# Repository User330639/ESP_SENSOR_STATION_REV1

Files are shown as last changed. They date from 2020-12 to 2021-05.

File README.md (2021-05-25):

# ESP_SENSOR_STATION_REV1
## Аннотация
Курсовой проект. ESP8622 (модуль ESP-12E) с набором датчиков:
 * Датчик температуры на основе SHT10
 * Датчик влажности на основе SHT10
 * Датчик концентрации пыли - AFE на AD7792
 * Датчик давления - AFE на AD7792
 * Датчик концентрации C3H8 - AFE на AD7792 
 
Основные особенности:
 * Питание от USB и/или от сети 230VAC, переключение между источниками без прерывания работы устройства
 * Программирование напрямую из среды разработки: BOOT и RESET ESP-12E управляются через RTS и DTR преобразователя USB-UART
 * Измерение концентрации C3H8 с применением прецизионного источника тока

Если опустить ряд низкоуровневых подробностей, софт занимается сбором данных с датчиков и по запросу выдает HTML страницу, содержащую примитивный интерфейс, в котором отображаются их показания. **Программная часть проекта не претендует на законченность и является в б*о*льшей мере демонстрацией возможностей устройства.**

## Структура репозитория
Репозиторий содержит 3 папки:  
**HW** - папка с проектом аппаратной части; выходные данные для производства содержатся в подкаталоге OUT.  
**SW** - папка с проектом программной части.  
**MECH** - проект корпуса устройства.  
Структура репозитория может претерпевать изменения по мере развития проекта.

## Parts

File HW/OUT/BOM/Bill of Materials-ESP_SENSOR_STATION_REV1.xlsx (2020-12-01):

LibRef | Description | Designator | Quantity
GRM188R61A226ME15D |  | C1, C2, C3, C4, C5, C6, C7, C9, C10, C11, C12, C13, C14, C15, C16 | 15
GRM1885C2A102JA01D |  | C8, C17, C18 | 3
GP2Y1010AU0F |  | DA1 | 1
AD7792 |  | DA2 | 1
IRM-05-5 |  | DA3 | 1
TPS2113APW |  | DA4 | 1
ADP3338AKCZ-3.3RL7 |  | DA5 | 1
MPXHZ6400AC6T1 |  | DA6 | 1
SHT10 |  | DA7 | 1
MP-5 |  | DA8 | 1
ESP-12E |  | DD1 | 1
CP2102-GMR |  | DD2 | 1
BLM18PG471SN1D |  | FB1, FB2 | 2
PKM22EPPH4007-B0 |  | Q1 | 1
RC0603FR-074K7L |  | R1, R3, R4, R5, R6, R9, R11, R12, R20, R25, R30, R35 | 12
RC0603FR-070RL |  | R2, R8, R27, R34, R36 | 5
RC0603FR-07510RL |  | R7 | 1
RC0603FR-071KL |  | R10, R21, R26 | 3
RC0603FR-07120RL |  | R13, R14, R15, R16, R17, R18, R19, R22, R23, R24, R28, R29, R31, R32, R33 | 15
B72214S0251K101 |  | RV1, RV2, RV3 | 3
5011 |  | TP1, TP2 | 2
GNL-3012GD |  | VD1 | 1
GNL-3012ED |  | VD2 | 1
SP0503BAHTG |  | VD3 | 1
2N7002LT1G |  | VT1, VT3, VT4, VT5 | 4
BC847BDW1T1G |  | VT2 | 1
300-031-12 |  | XS1 | 1
1734035-1 |  | XS2 | 1
B6B-ZR-SM4-TF(LF)(SN) |  | XS3 | 1

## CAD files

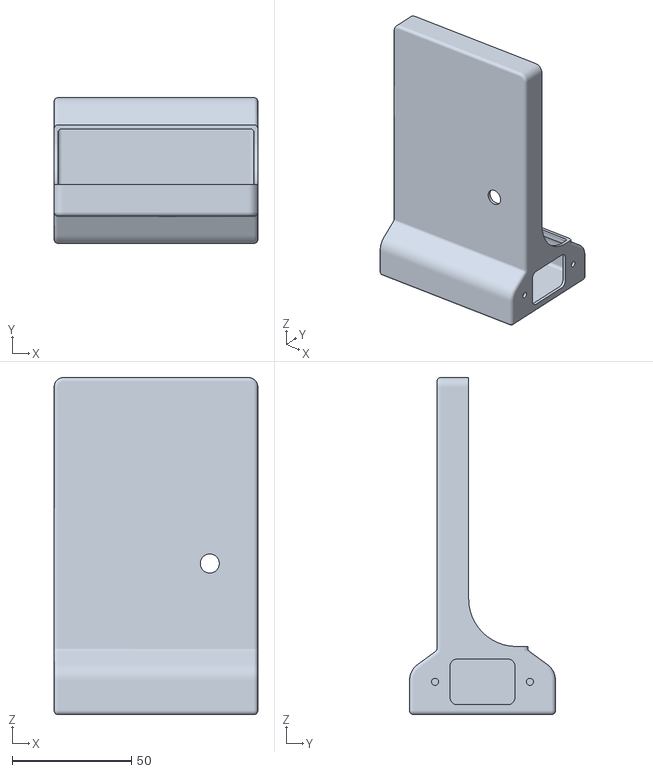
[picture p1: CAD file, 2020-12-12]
MECH/Основание.stl
85.5 x 61.2 x 141.5

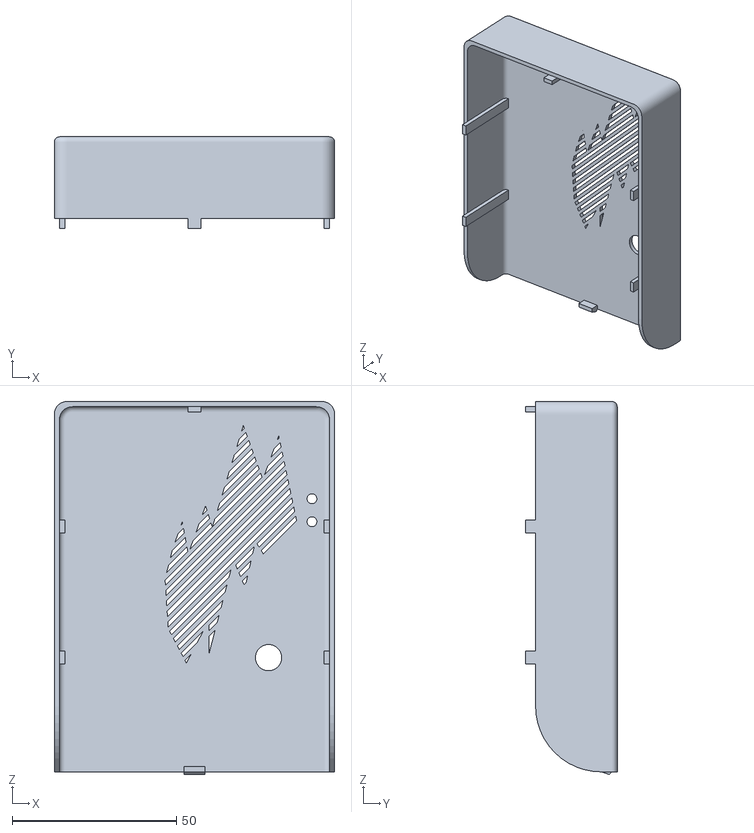
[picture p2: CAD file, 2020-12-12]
MECH/Крышка.stl
85.5 x 27.9 x 113.7

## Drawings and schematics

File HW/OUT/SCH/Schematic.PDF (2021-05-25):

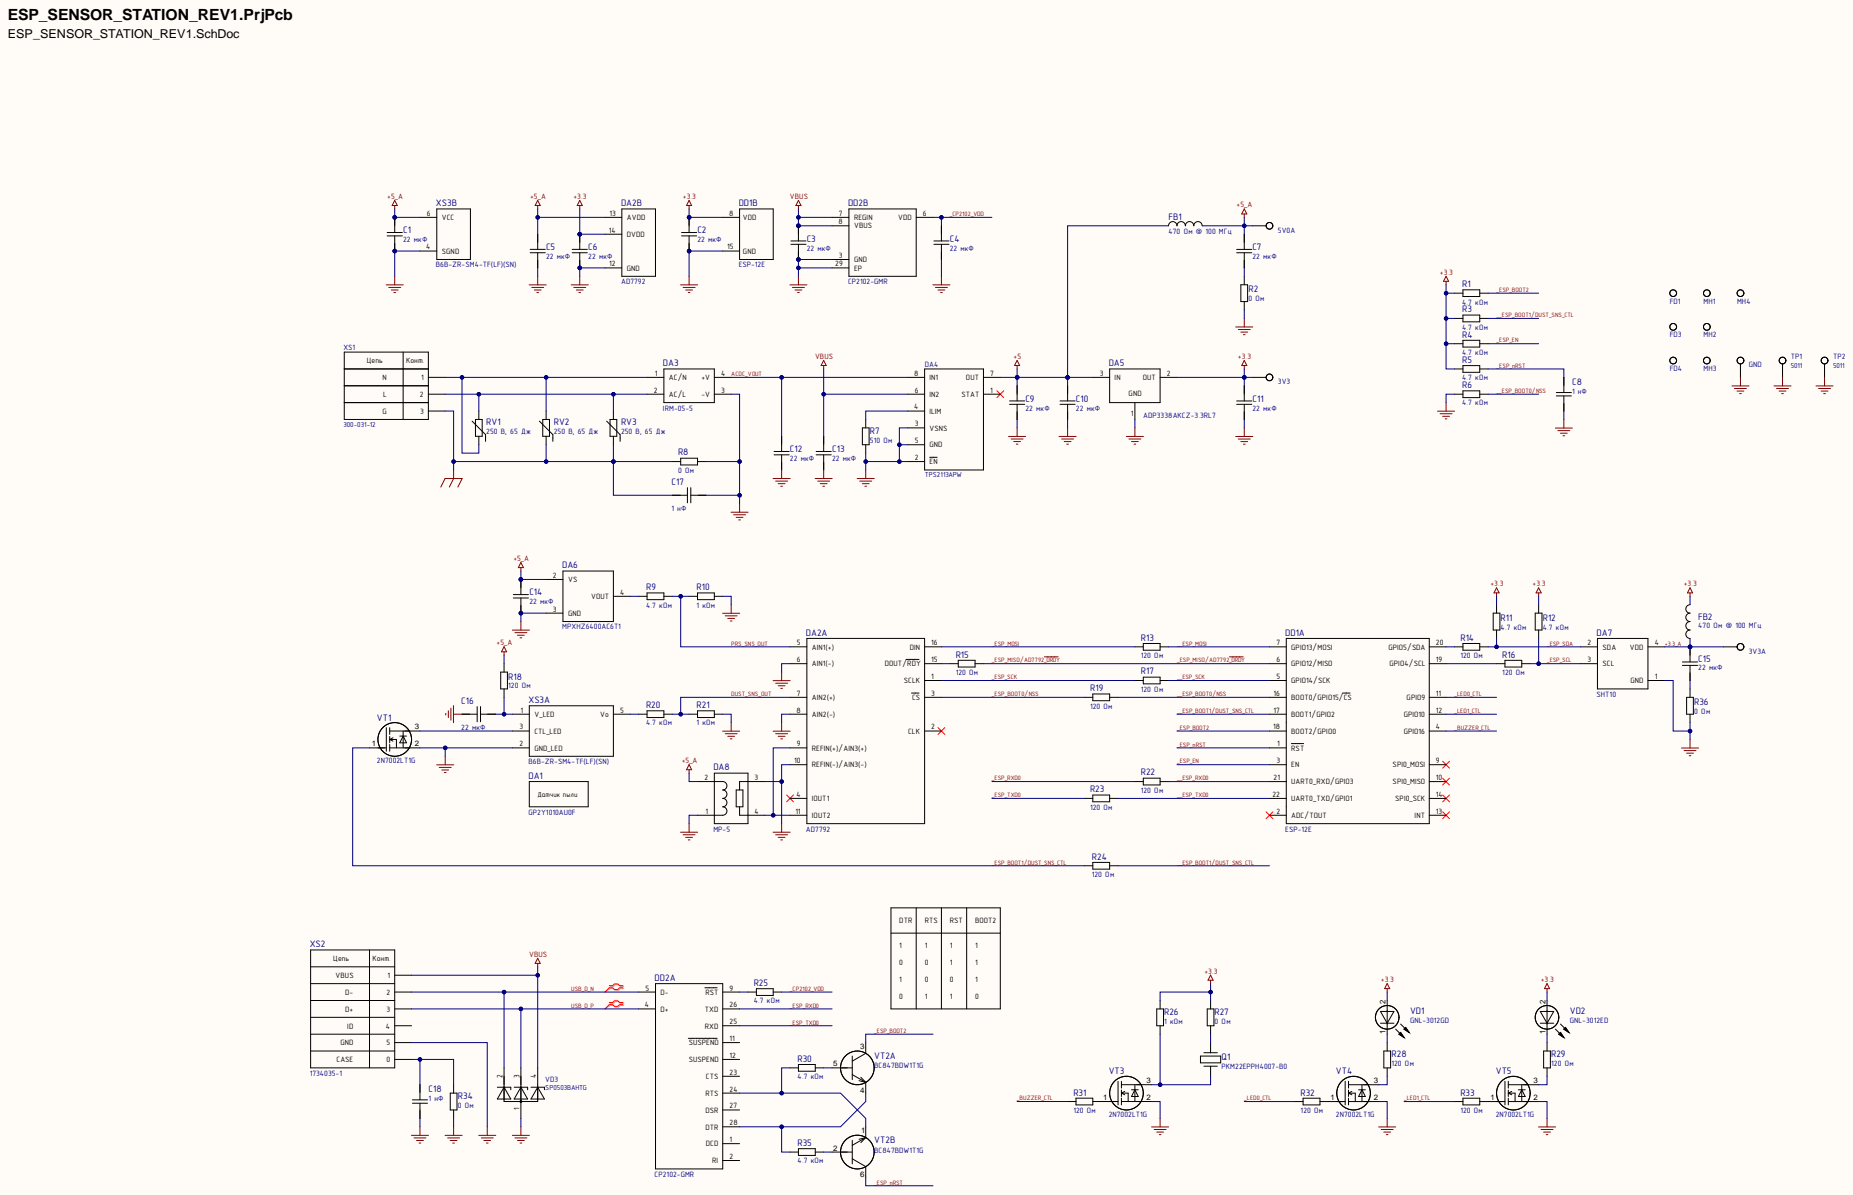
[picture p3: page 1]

ILIM 4

VSNS 3

GND 5

2 | GND_LED 2

REFIN(-)/AIN3(-) 10

IOUT2 11 | | ADC/TOUT 2

DTR | RTS | RST | BOOT2

Цепь | Конт.

VBUS | 1

USB_D_P | D+ 4 | _ESP_RXD0

GND | 5

CASE | 0

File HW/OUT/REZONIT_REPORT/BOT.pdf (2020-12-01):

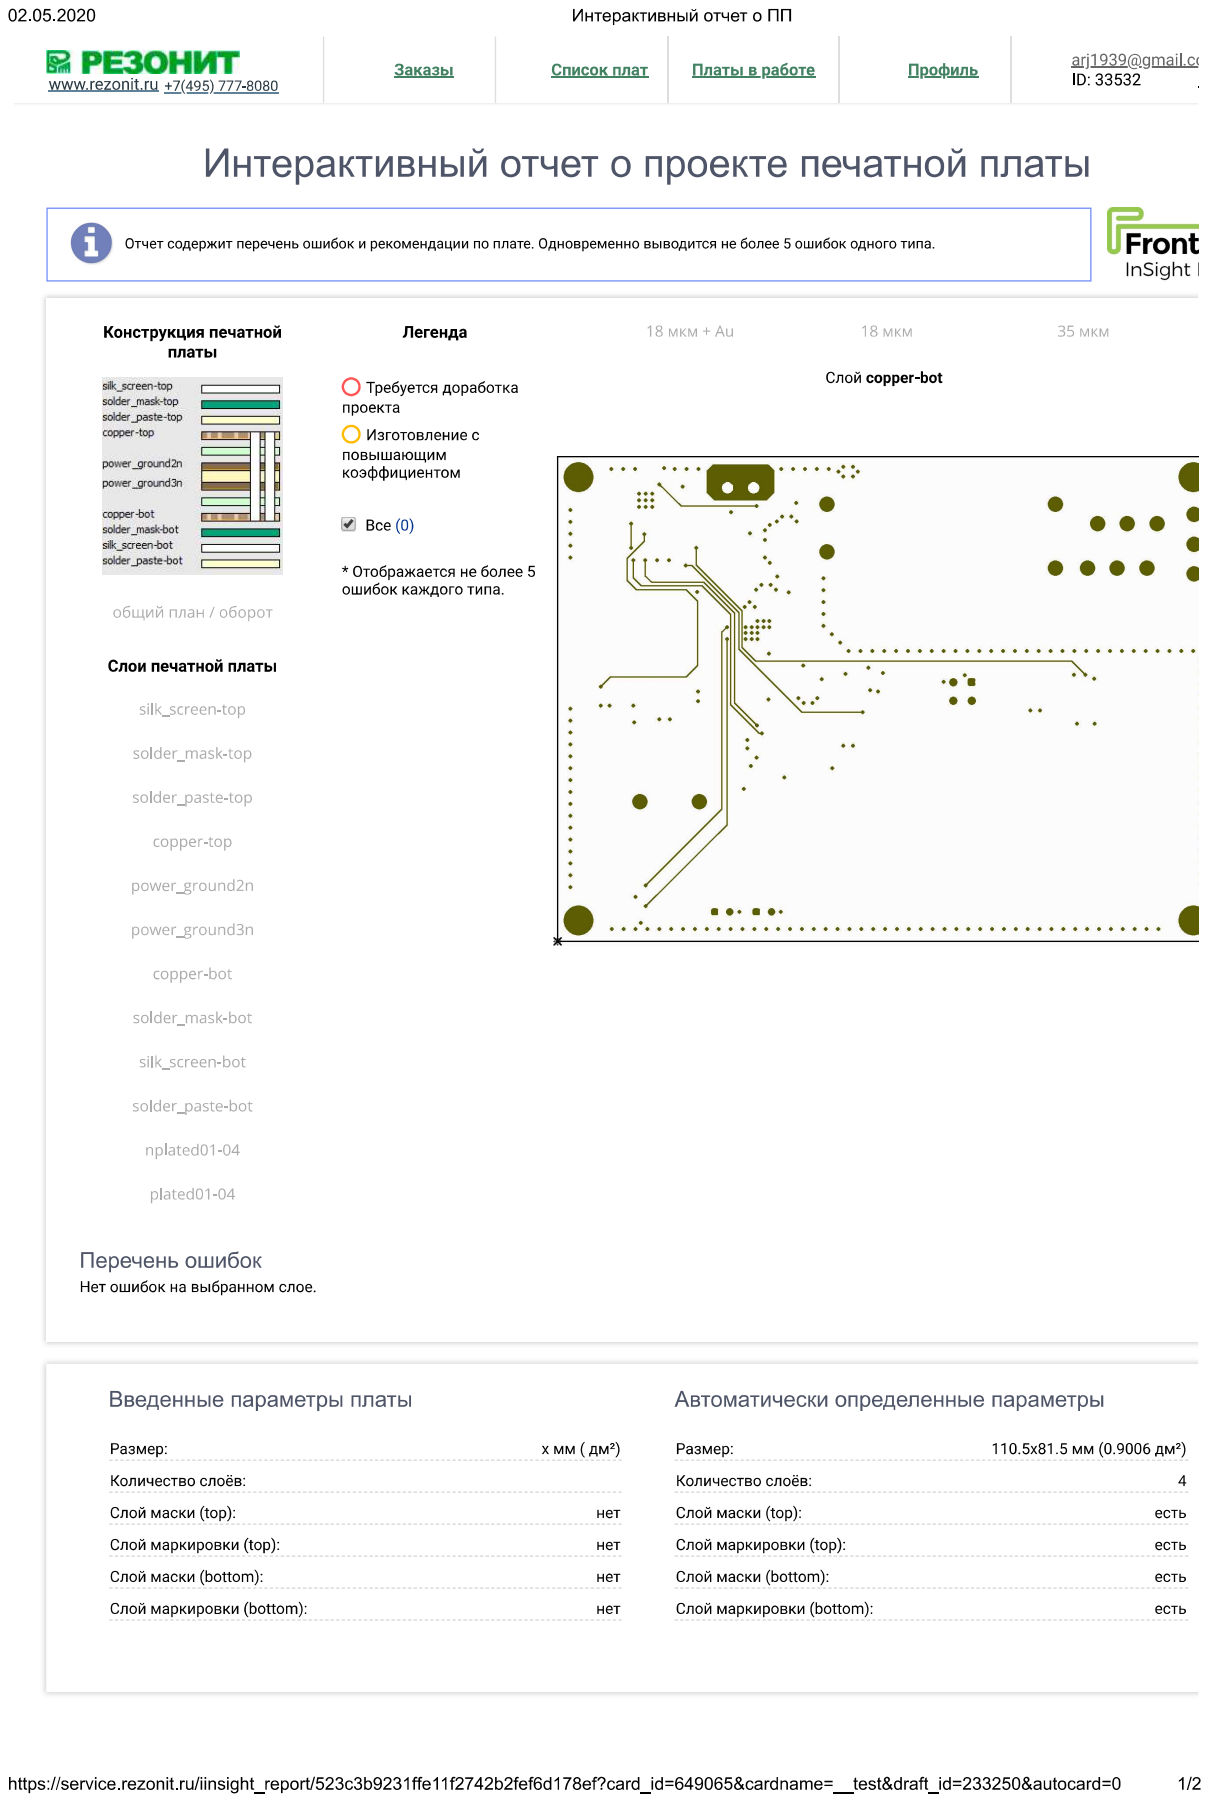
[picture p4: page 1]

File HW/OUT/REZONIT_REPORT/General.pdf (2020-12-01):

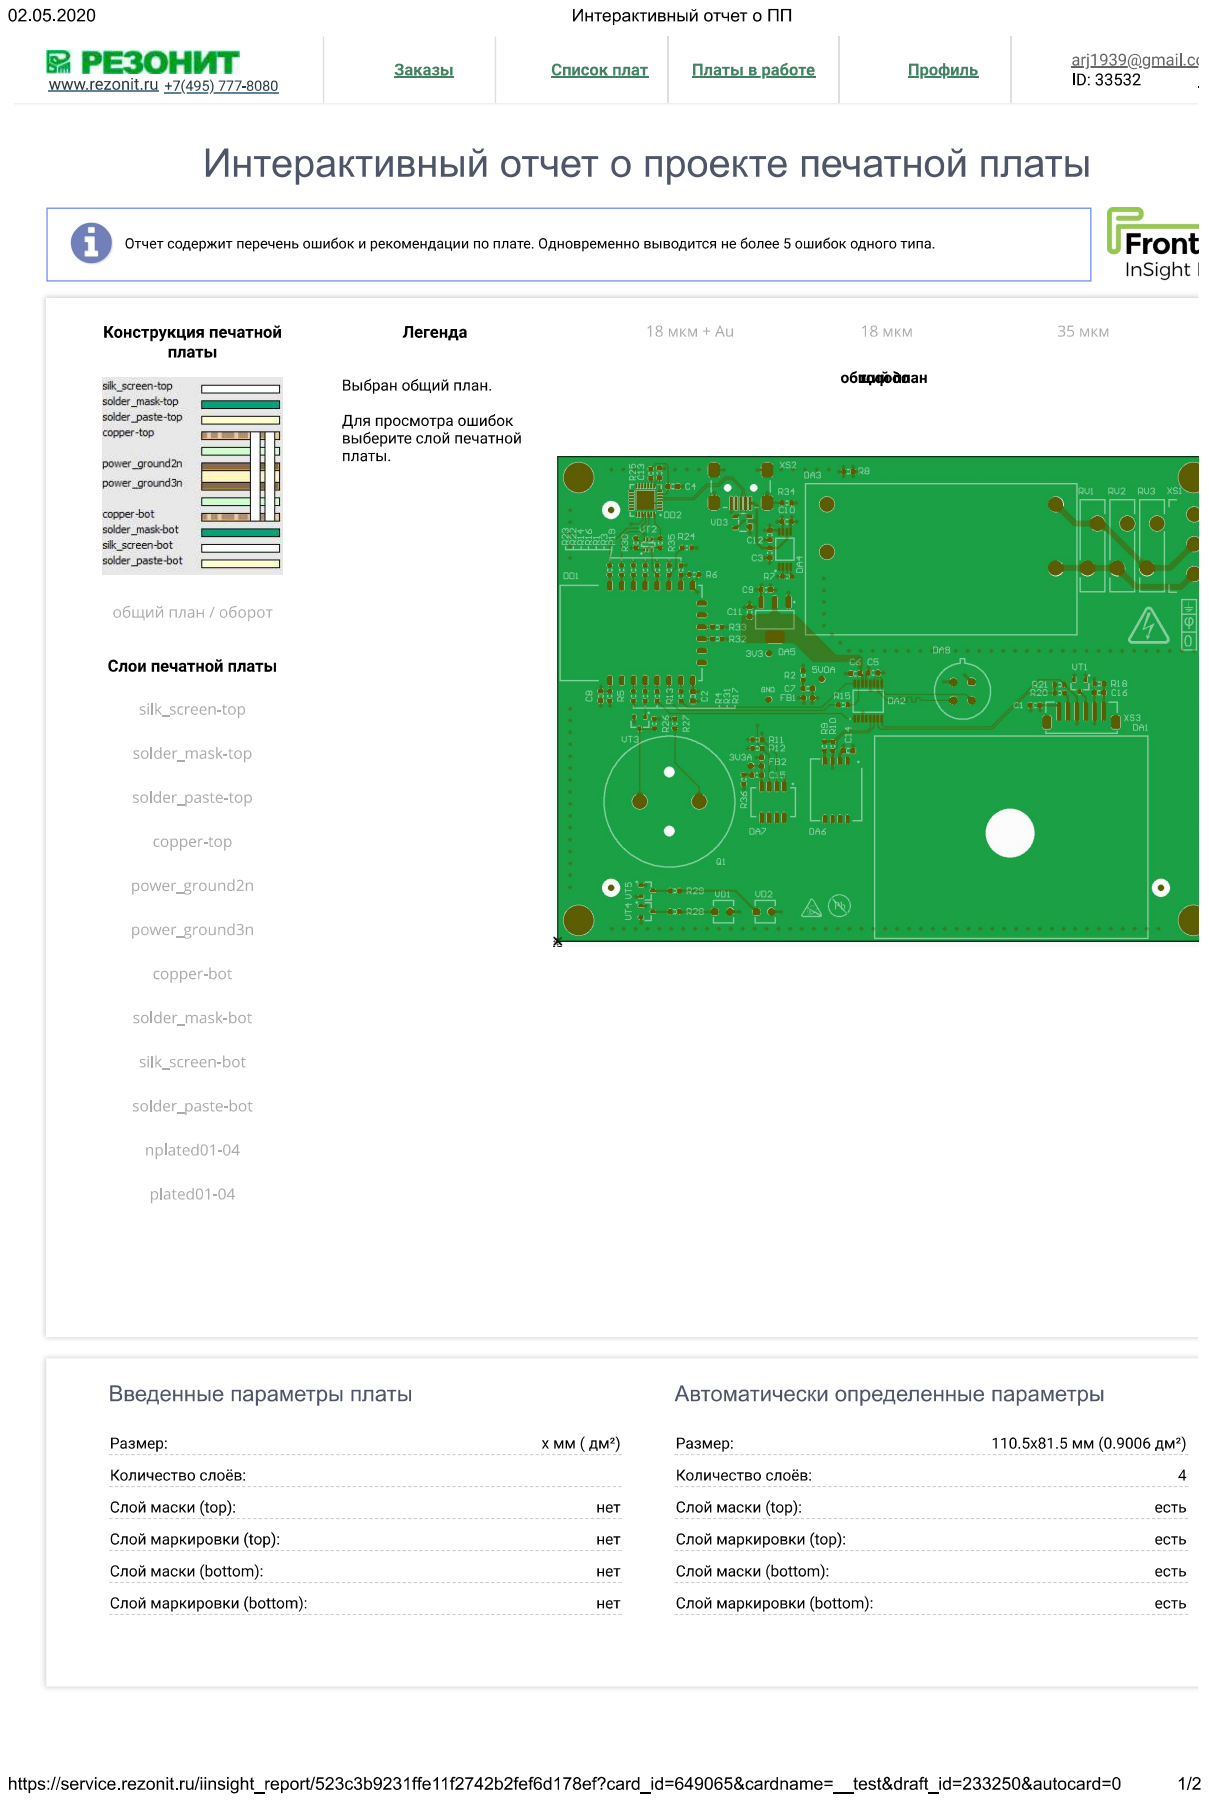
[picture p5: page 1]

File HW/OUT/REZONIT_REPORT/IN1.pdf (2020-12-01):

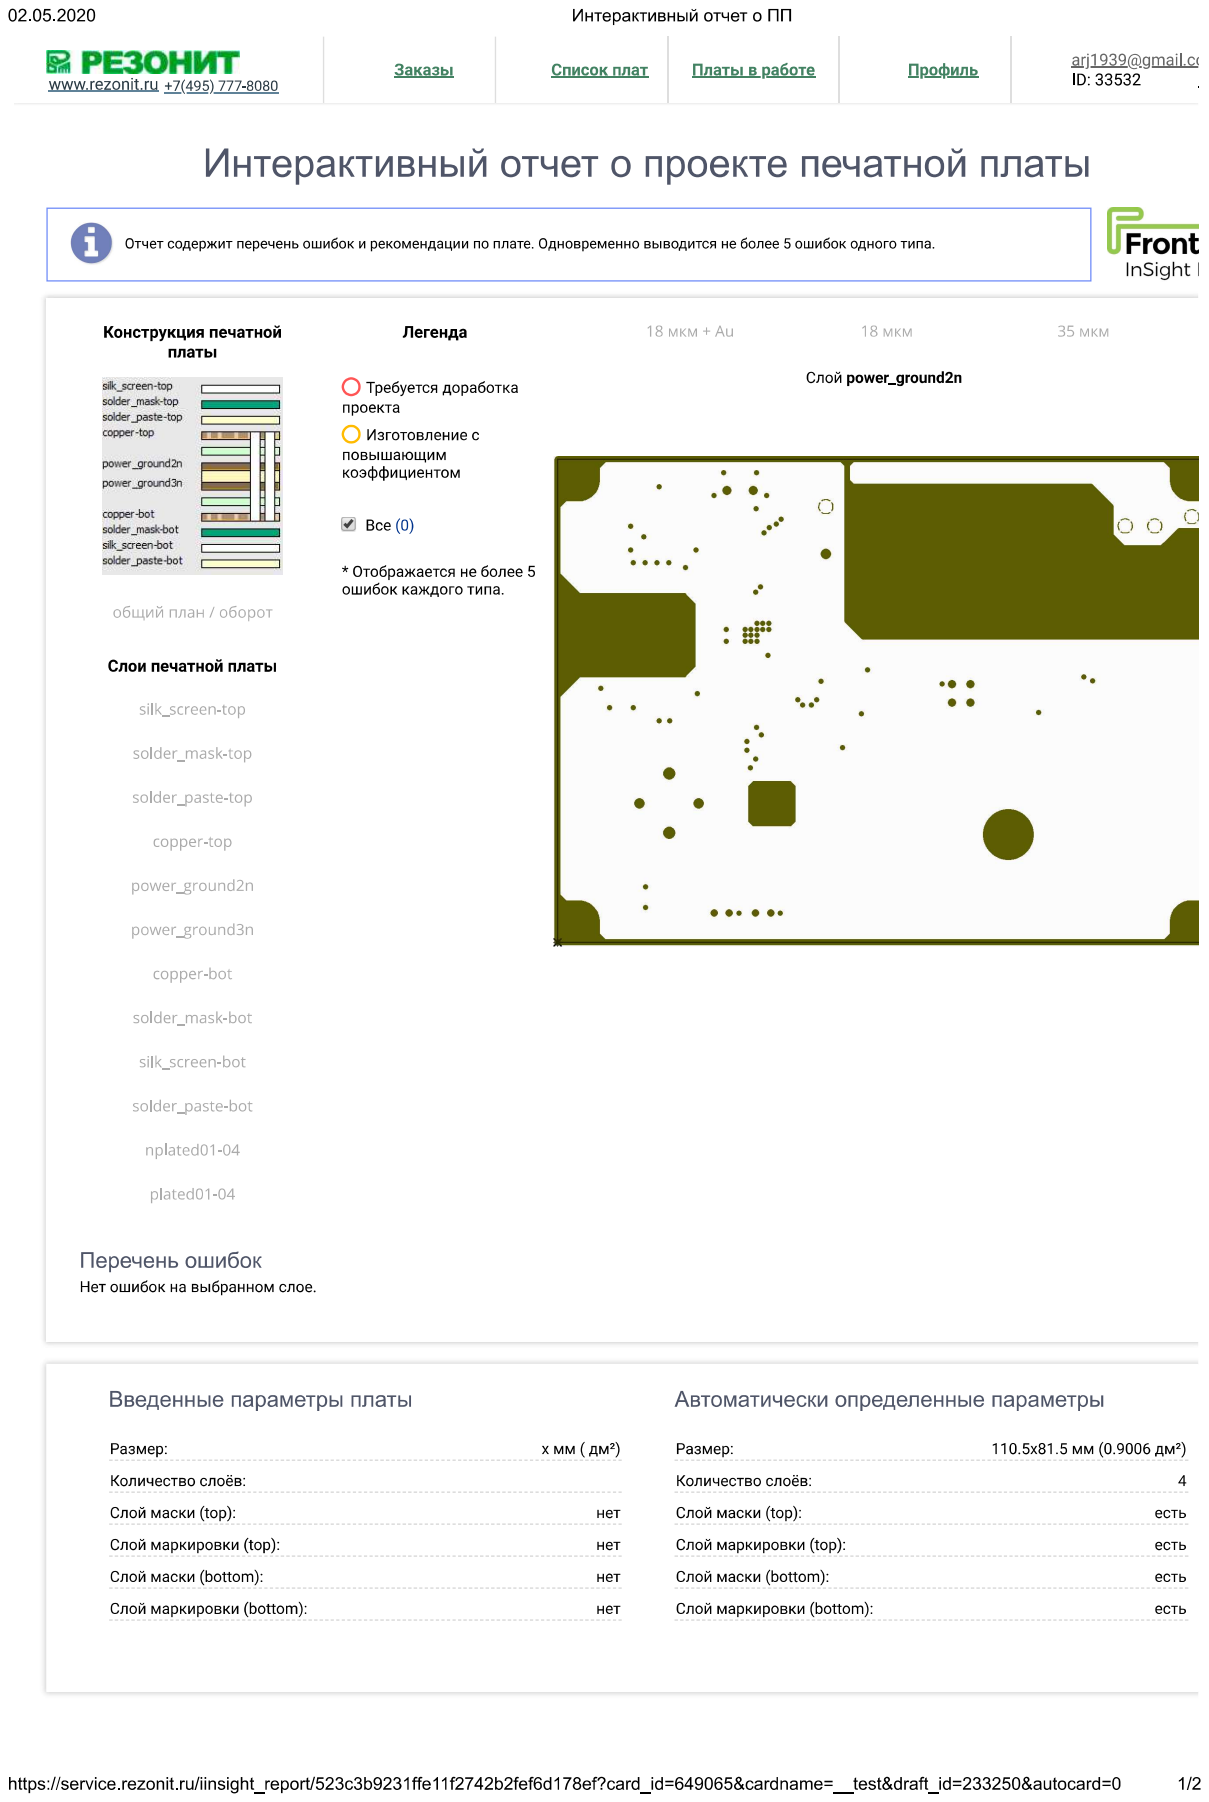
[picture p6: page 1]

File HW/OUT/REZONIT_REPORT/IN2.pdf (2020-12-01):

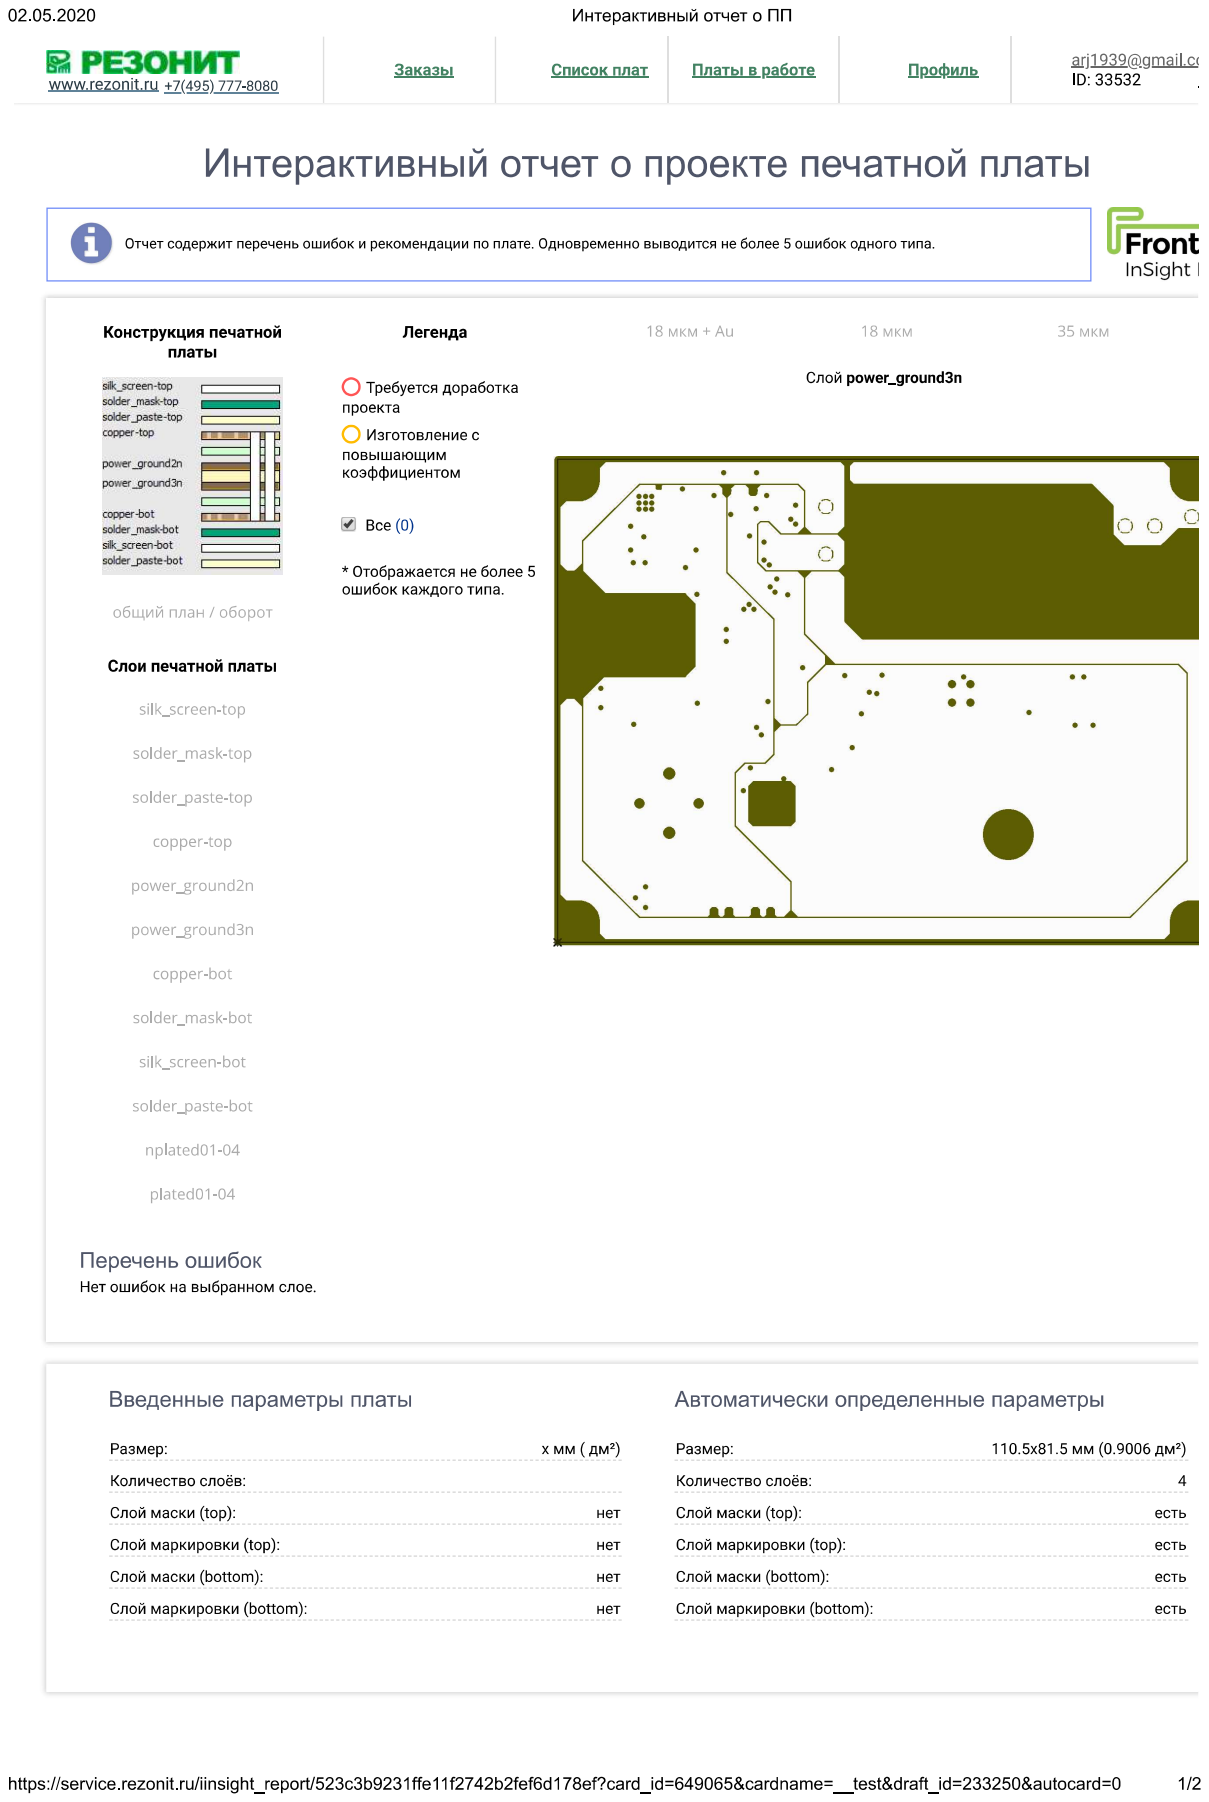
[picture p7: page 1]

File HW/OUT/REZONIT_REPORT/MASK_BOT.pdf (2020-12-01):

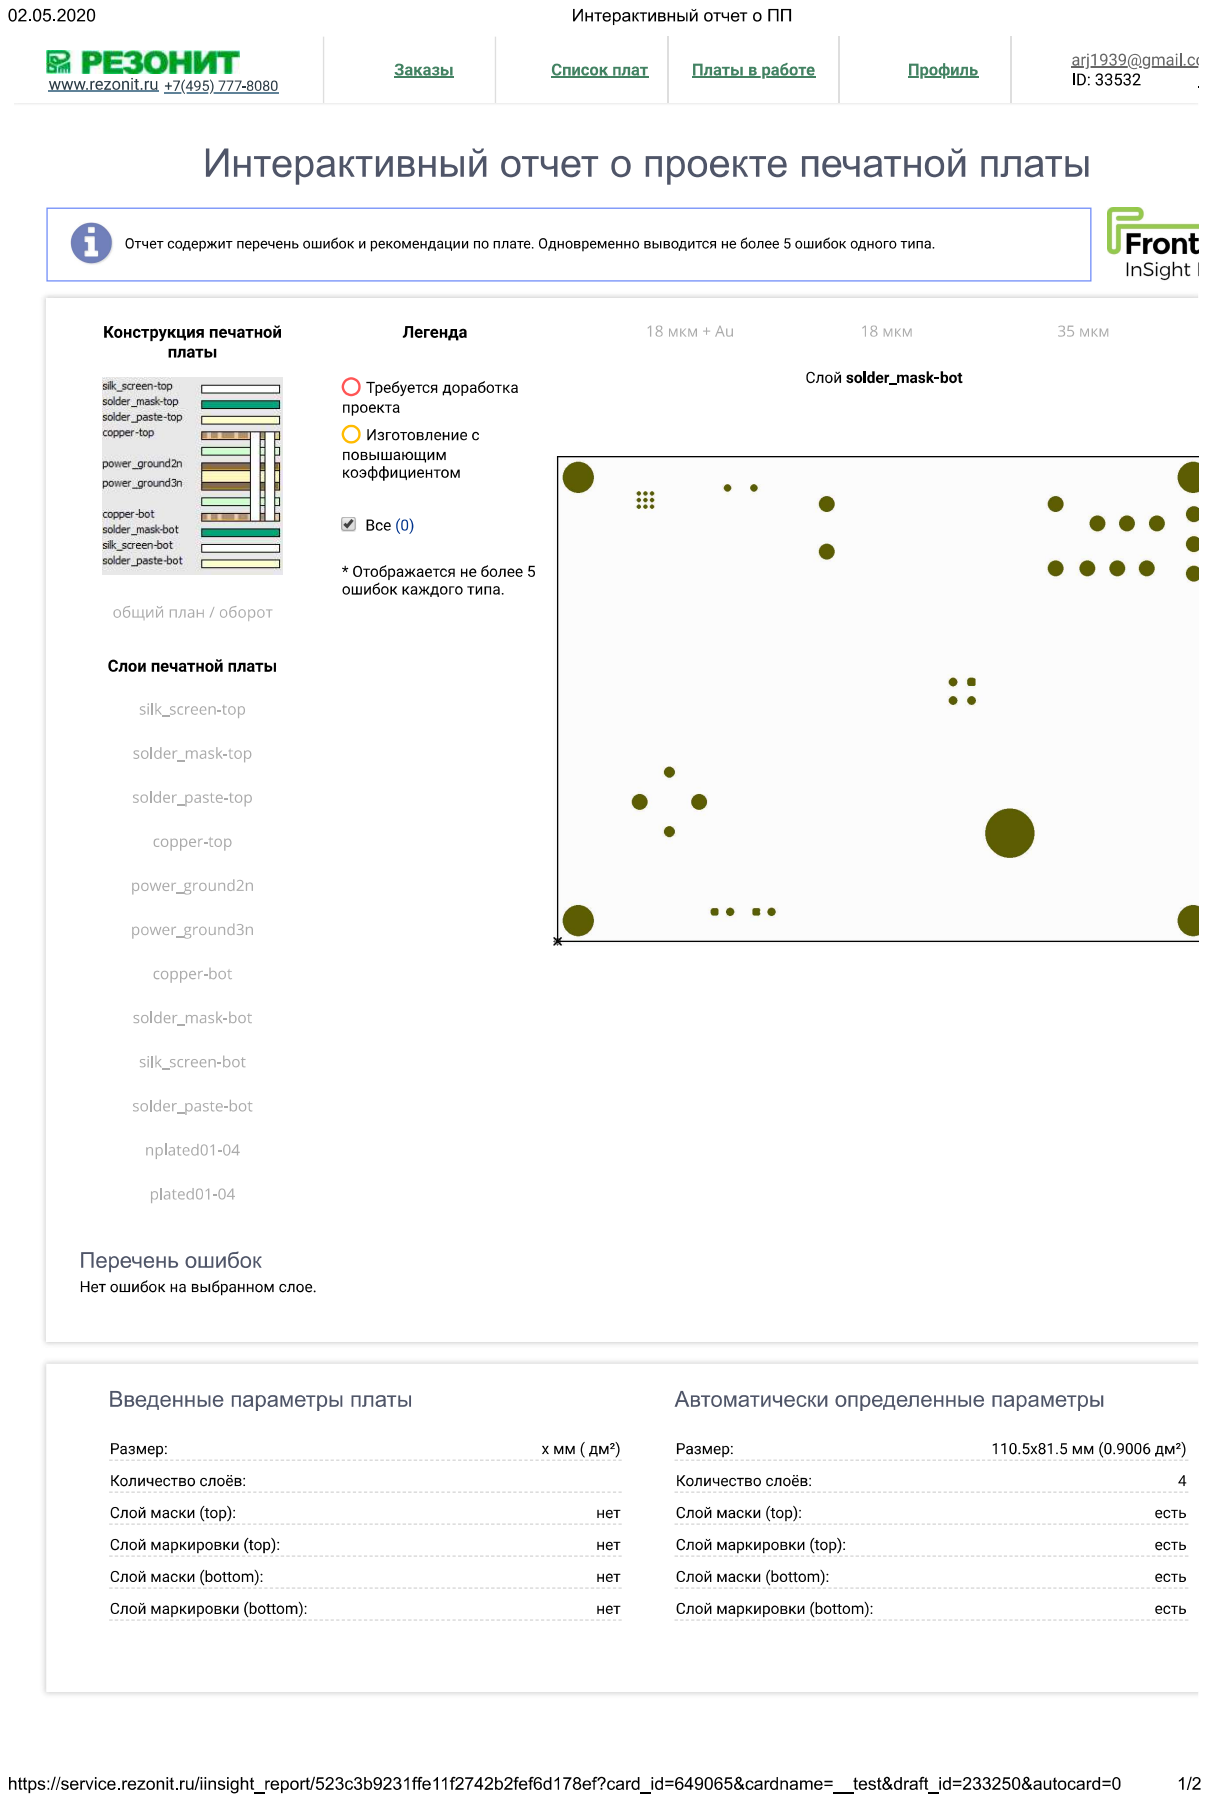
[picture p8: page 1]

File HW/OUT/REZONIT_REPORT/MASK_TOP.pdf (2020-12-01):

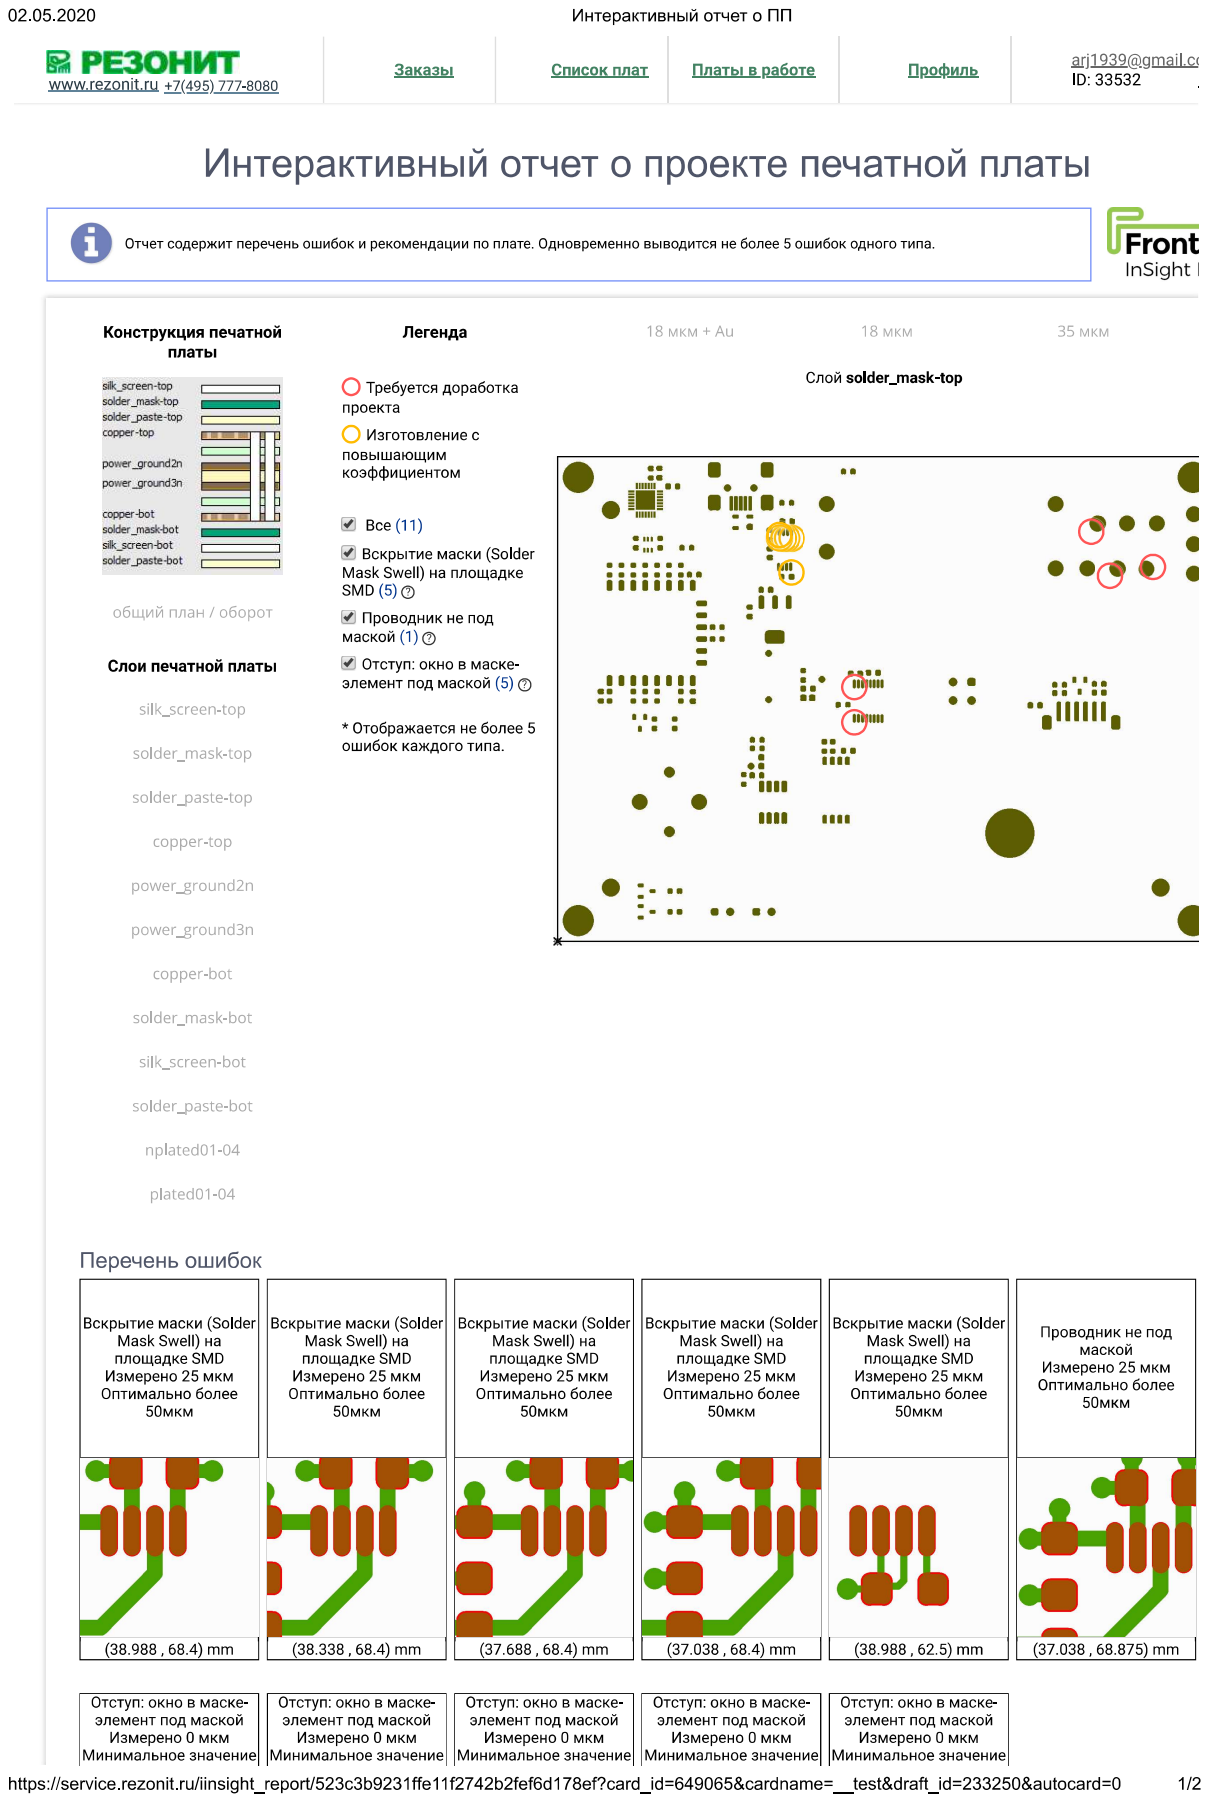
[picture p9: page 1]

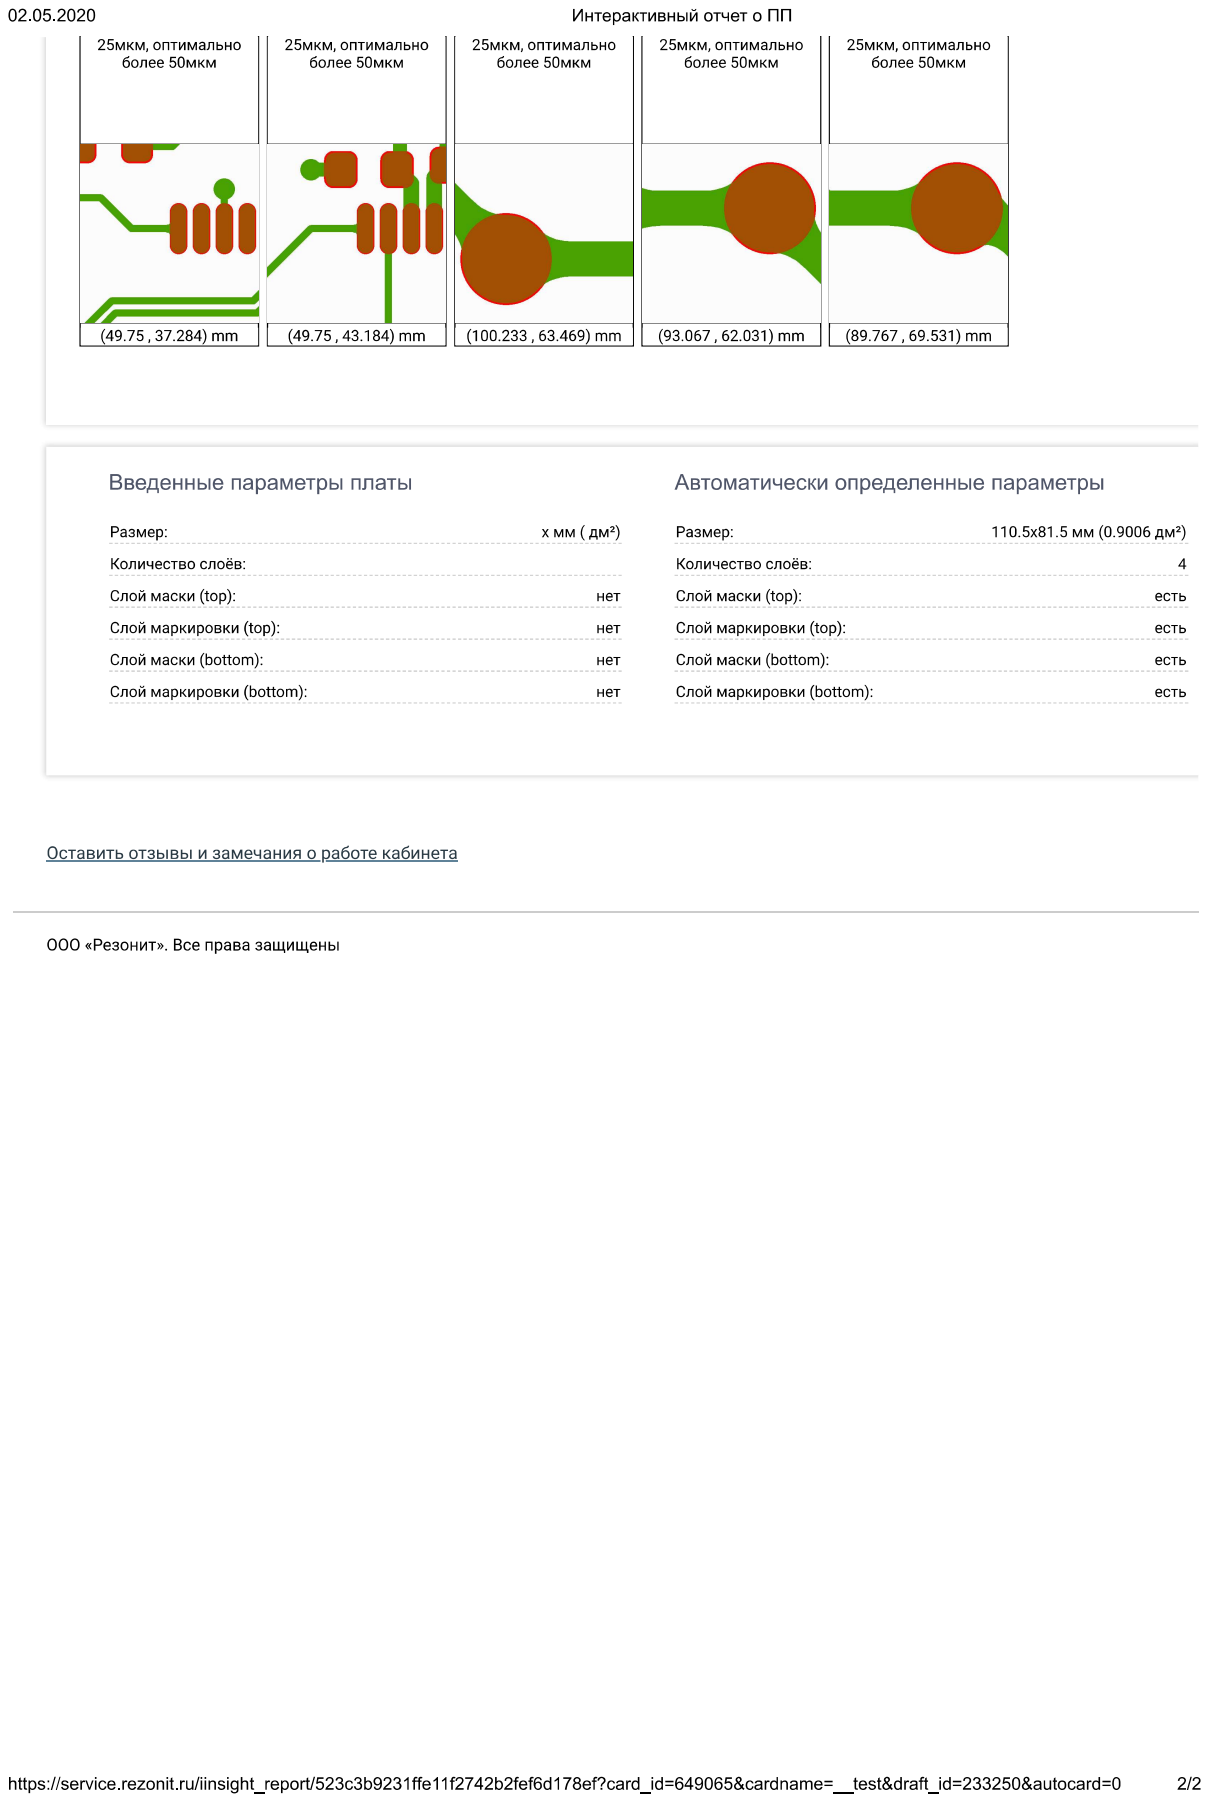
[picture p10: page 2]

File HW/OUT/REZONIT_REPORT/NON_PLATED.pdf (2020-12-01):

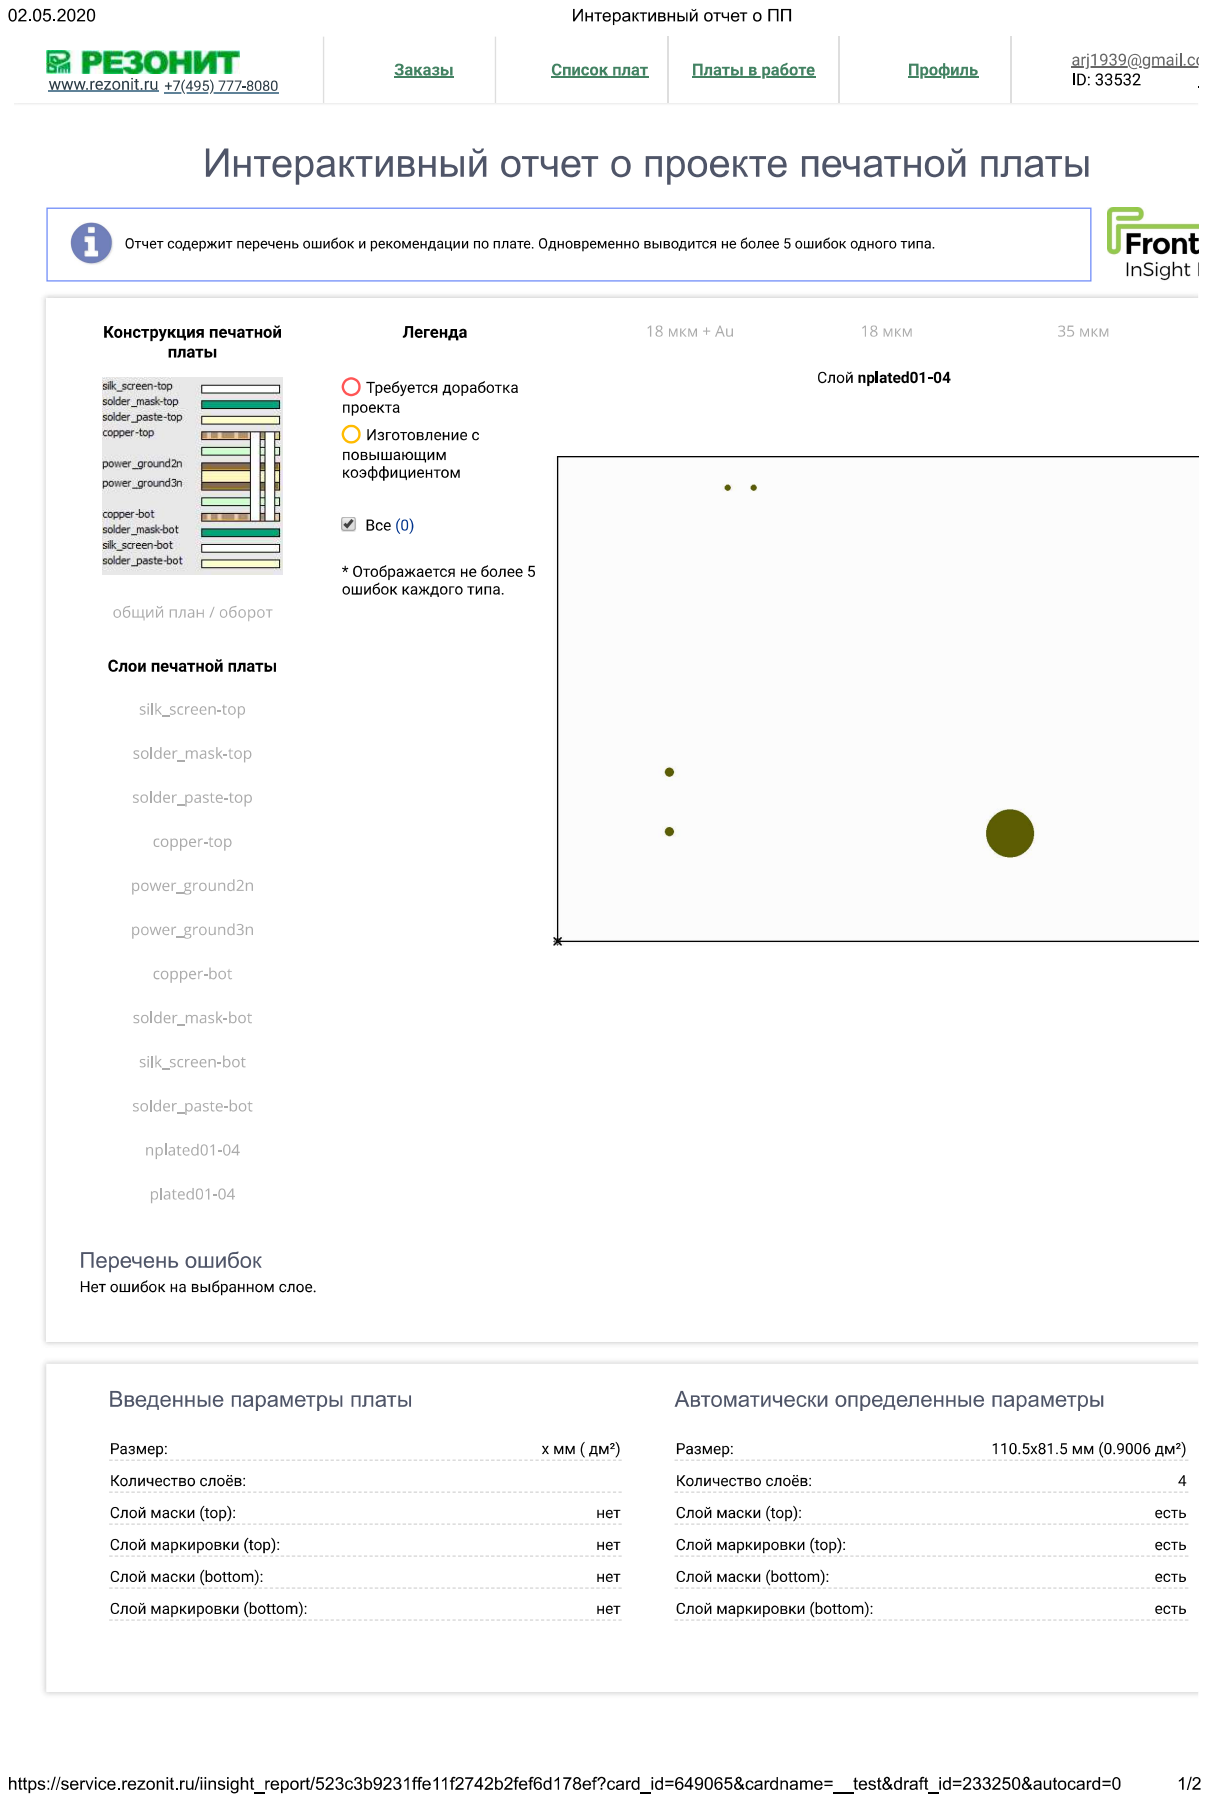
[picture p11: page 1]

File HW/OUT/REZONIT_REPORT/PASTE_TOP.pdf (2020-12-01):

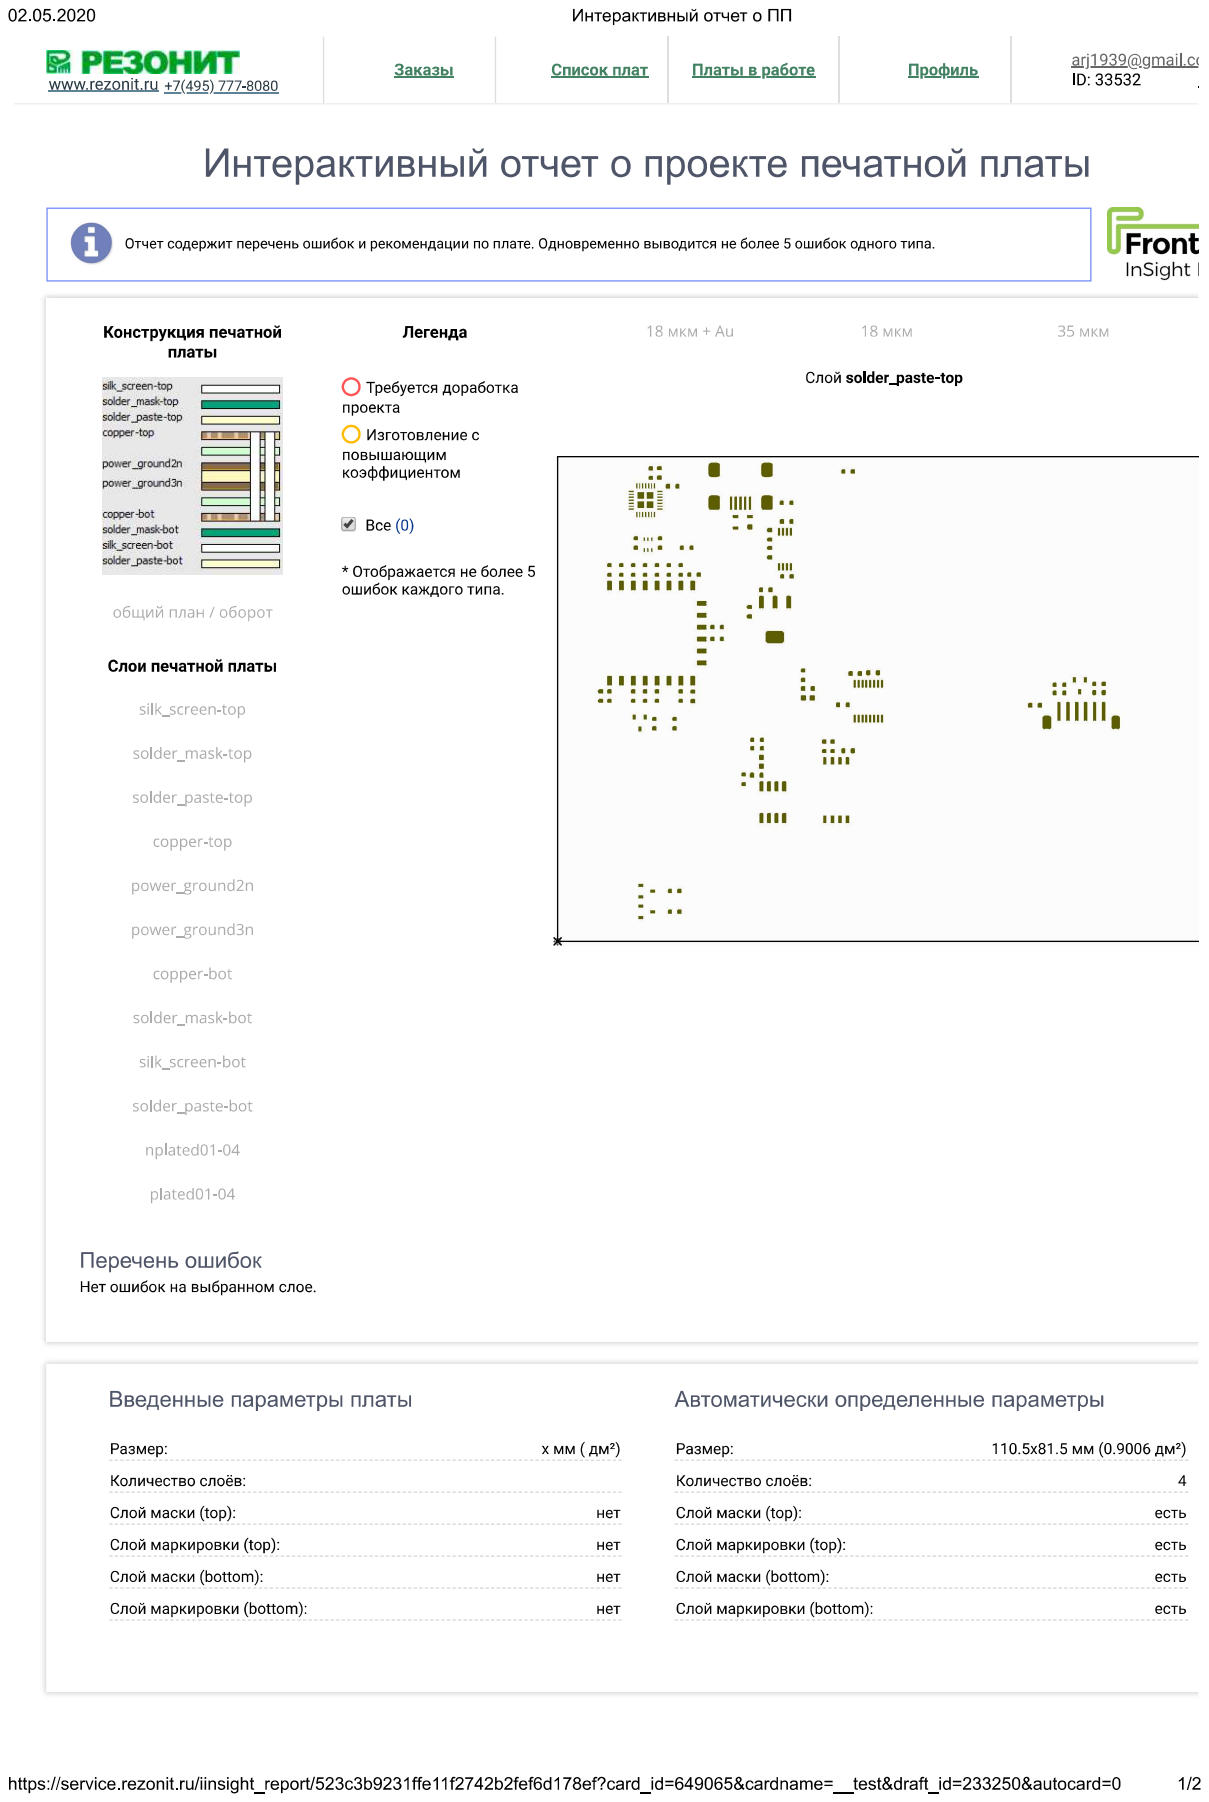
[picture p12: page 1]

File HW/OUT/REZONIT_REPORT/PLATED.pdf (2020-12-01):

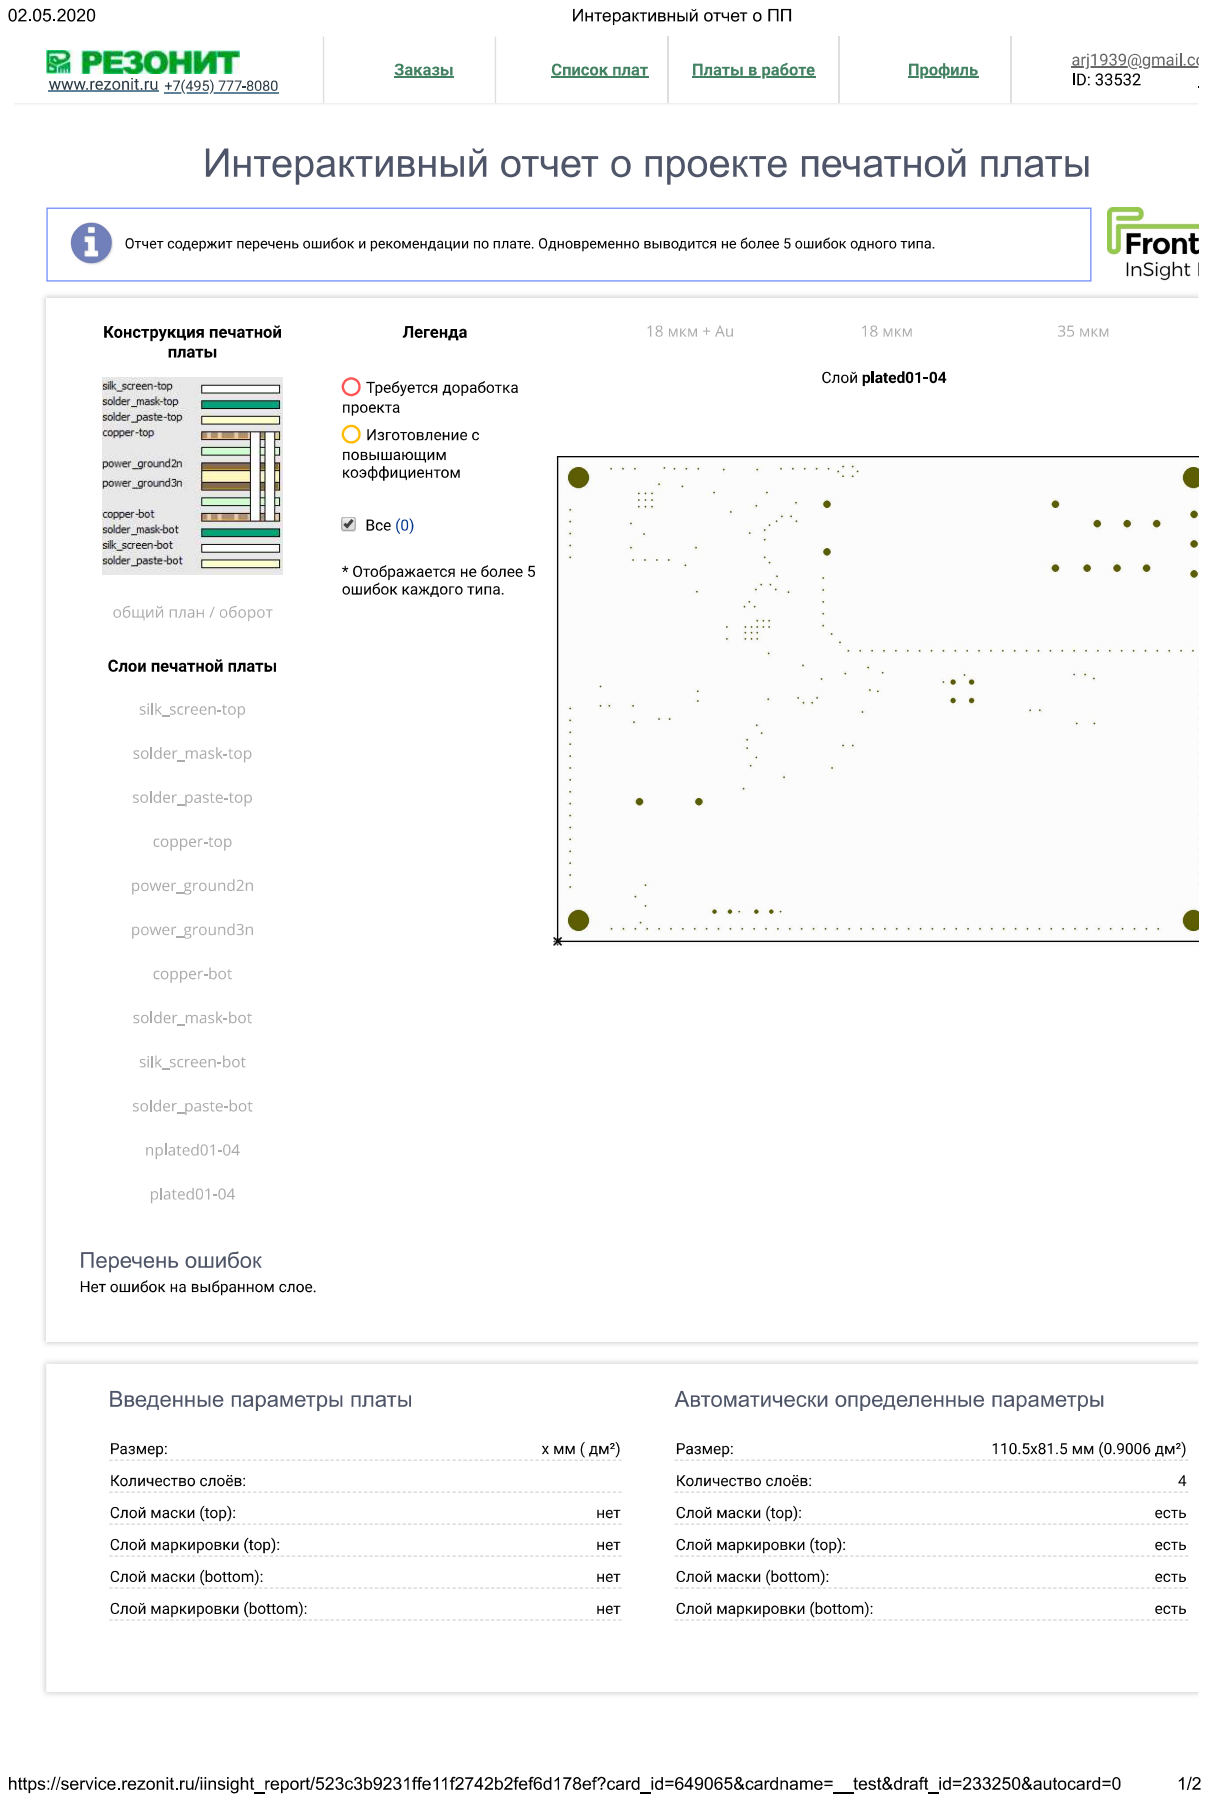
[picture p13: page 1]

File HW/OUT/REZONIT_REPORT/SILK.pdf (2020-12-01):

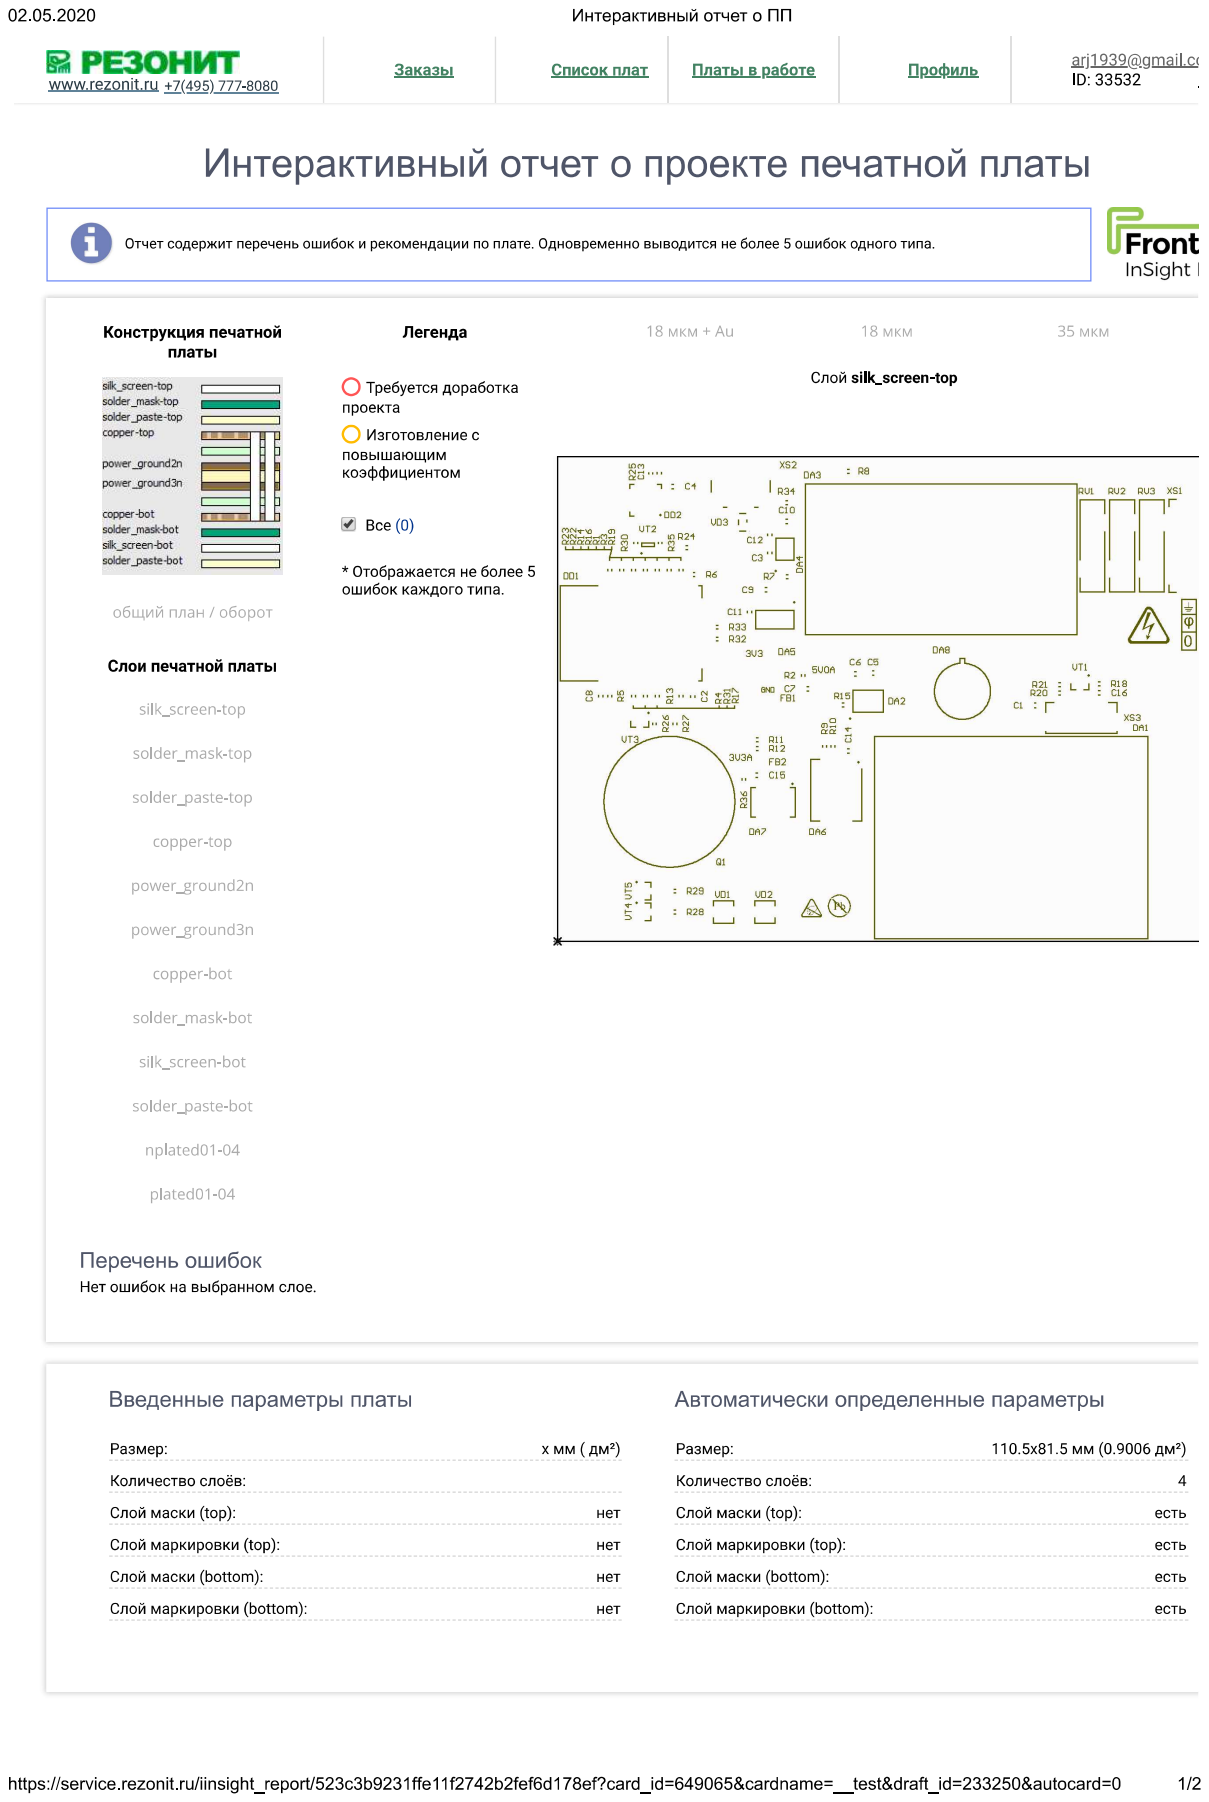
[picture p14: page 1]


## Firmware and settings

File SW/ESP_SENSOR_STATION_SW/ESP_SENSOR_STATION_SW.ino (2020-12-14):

#include <ESP8266WiFi.h>
#include <ESP8266WebServer.h>
#include <Task.h>
#include "webPage.h"
#include "AD7792.h"
#include "SHT1x.h"

/* ESP creates WiFi network with this SSID password combination */
#define _SSID "TEST"
#define _PASS "12345678"
/* ------------------------------------------------------------ */

/* STH1x driver uses GPIO for communication; these definitions  */
/* denote GPIO pins used for that purpose                       */
#define SHT1x_dataPin  5
#define SHT1x_clockPin 4

/* Macros for lesser verbosity; corresponidng methods return    */
/* float values                                                 */
#define GET_TMP        (SHT1x.readTemperature(TempUnit::C))
#define GET_HUM        (SHT1x.readHumidity())

#define BUZZER_GPIO    16
#define BUZZER_OFF     analogWrite(BUZZER_GPIO, 0)
#define BUZZER_ON      analogWrite(BUZZER_GPIO, 127);

#define LED0_GPIO      9  // Normal opeartion LED
#define LED1_GPIO      10 // Alarm LED

#define DUST_SNS_GPIO  2
/* ------------------------------------------------------------ */

/* Raw-to-values macros and definitions                         */
#define AD7792_INT_VREF           1.17f
#define AD7792_MAX_CODE           65535UL
#define AD7792_INPUT_VOLTAGE(raw) ((float)raw * AD7792_INT_VREF / (float)AD7792_MAX_CODE)

#define V_TO_PRESSURE(v)          ((float)v * 5.7f / (5.0f * 0.002421f) + 0.00848f)
#define PRS_UNITS                 "kPa"

#define V_TO_C_DUST(v)            (0.07f + 0.33f * ((float)v * 5.7f - 1.0f) / 2.0f)
#define DUST_UNITS                "mg/m3"

#define C3H8_V_TO_R(v)            ((float)v / 10e-6)
#define C3H8_R0                   40000.0f
#define C3H8_R_TO_PPM(r)          exp(4.9012f + 0.0036f * ((float)r / C3H8_R0)) // exponential regression
#define C3H8_UNITS                "ppm"
/* ------------------------------------------------------------ */

#define TEMPERATURE_ALARM_TRESHLD_LO 0.0f
#define TEMPERATURE_ALARM_TRESHLD_HI 40.0f
#define HUMIDITY_ALARM_TRESHLD_LO    5.0f
#define HUMIDITY_ALARM_TRESHLD_HI    80.0f
#define PRESSURE_ALARM_TRESHLD_LO    80.0f
#define PRESSURE_ALARM_TRESHLD_HI    120.0f
#define C3H8_ALARM_TRESHLD_LO        0.0f
#define C3H8_ALARM_TRESHLD_HI        500.0f
#define CDUST_ALARM_TRESHLD_LO       0.0f
#define CDUST_ALARM_TRESHLD_HI       1.0f
#define ALARM_CONDITION                                                             \
(                                                                                   \
  (tmp  > TEMPERATURE_ALARM_TRESHLD_HI) || (tmp  < TEMPERATURE_ALARM_TRESHLD_LO) || \
  (hum  > HUMIDITY_ALARM_TRESHLD_HI)    || (hum  < HUMIDITY_ALARM_TRESHLD_LO)    || \
  (prs  > PRESSURE_ALARM_TRESHLD_HI)    || (prs  < PRESSURE_ALARM_TRESHLD_LO)    || \
  (c3h8 > C3H8_ALARM_TRESHLD_HI)        || (c3h8 < C3H8_ALARM_TRESHLD_LO)        || \
  (dust > CDUST_ALARM_TRESHLD_HI)       || (dust < CDUST_ALARM_TRESHLD_LO)          \
)

/* Global objects and variables                                 */
ESP8266WebServer server(80); // The server hosts a webpage port #80; see webPage.h and webPage.cpp
SHT1x SHT1x(SHT1x_dataPin, SHT1x_clockPin); // Global SHT1x object; the constructor requires GPIO numbers used for communication
boolean _ad7792_present = false; // Global variable that indicates presence or absence of AD7792
boolean _sht10_present = false; // Global variable that indicates presence or absence of SHT1x
TaskManager taskManager; // Task manager used to put measurements/alarms and client handling into separate threads

float tmp  = std::numeric_limits<float>::quiet_NaN();
float hum  = std::numeric_limits<float>::quiet_NaN();
float prs  = std::numeric_limits<float>::quiet_NaN();
float c3h8 = std::numeric_limits<float>::quiet_NaN();
float dust = std::numeric_limits<float>::quiet_NaN();

static const FlashMode_t ideMode = ESP.getFlashChipMode();
/* ------------------------------------------------------------ */

void dataUpdater(uint32_t deltaTime);
void clientHandler(uint32_t deltaTime);
void alarmOn(uint32_t deltaTime);

FunctionTask taskDataUpdater(dataUpdater, MsToTaskTime(100));
FunctionTask taskClientHandler(clientHandler, MsToTaskTime(1500));
FunctionTask taskAlarmOn(alarmOn, MsToTaskTime(500));


/* Returns the value of pressure in PRS_UNITS units             */
float GET_PRS()
{
  AD7792_SetChannel(AD7792_CH_AIN1P_AIN1M);
  unsigned long code = AD7792_ContinuousReadAvg(8);
  float sensor_voltage = AD7792_INPUT_VOLTAGE(code);
  return V_TO_PRESSURE(sensor_voltage);
}
/* ------------------------------------------------------------ */

/* Same as GET_PRS() but returns dust concentration             */
float GET_DUST()
{
  digitalWrite(DUST_SNS_GPIO, HIGH);
  delay(1);
  AD7792_SetChannel(AD7792_CH_AIN2P_AIN2M);
  unsigned long code = AD7792_ContinuousReadAvg(8);
  float sensor_voltage = AD7792_INPUT_VOLTAGE(code);
  delay(1);
  digitalWrite(DUST_SNS_GPIO, LOW);
  return V_TO_C_DUST(sensor_voltage);
}
/* ------------------------------------------------------------ */

/* Same as GET_PRS() but returns C3H8 concentration             */
float GET_C3H8()
{
  AD7792_SetChannel(AD7792_CH_AIN3P_AIN3M);
  unsigned long code = AD7792_ContinuousReadAvg(8);
  float sensor_voltage = AD7792_INPUT_VOLTAGE(code);
  float sensor_resistance = C3H8_V_TO_R(sensor_voltage);
  return C3H8_R_TO_PPM(sensor_resistance);
}
/* ------------------------------------------------------------ */

/* Creates webpage and sends it as responce to the client       */
void handleRoot()
{
  String str = Make_page();
  server.send(200, "text/html", str); //Send web page
}
/* ------------------------------------------------------------ */

/* Collects data from sensors if present;                       */
/* if no devices were detected during setup, assigns NaN;       */
/* sends data to the client once it is available                */
void data()
{
  /* Generates and sends responce to the client */
  char Str[512];
  sprintf(Str, "<br>Temperature: %.2f oC<br/>       \
                <br>Pressure: %.2f %s<br/>          \
                <br>Humidity: %.2f %c</br>          \
                <br>C3H8: %.2f %s<br/>              \
                <br>Dust density: %.2f %s<br/>",    \ 
                tmp, prs, PRS_UNITS, hum, '%', c3h8, C3H8_UNITS, dust, DUST_UNITS);
  server.send(200, "text/plane", Str); 
}
/* ------------------------------------------------------------ */

void dataUpdater(uint32_t deltaTime)
{
  tmp  = std::numeric_limits<float>::quiet_NaN();
  hum  = std::numeric_limits<float>::quiet_NaN();
  prs  = std::numeric_limits<float>::quiet_NaN();
  c3h8 = std::numeric_limits<float>::quiet_NaN();
  dust = std::numeric_limits<float>::quiet_NaN();

  /* Gets data */
  if (_ad7792_present)
  {
    prs  = GET_PRS();
    c3h8 = GET_C3H8();
    dust = GET_DUST();
  }
  if (_sht10_present)
  {
    tmp  = GET_TMP;
    hum  = GET_HUM;
  }
  if (ALARM_CONDITION)
  {
    taskManager.StartTask(&taskAlarmOn);
  }
}

void clientHandler(uint32_t deltaTime)
{
  server.handleClient();
}

void alarmOn(uint32_t deltaTime)
{
#ifdef ESP_QSPI_DIO
  digitalWrite(LED1_GPIO, HIGH);
#endif
  BUZZER_ON;
  delay(75);
  BUZZER_OFF;
  delay(75);
  BUZZER_ON;
  delay(75);
  BUZZER_OFF;
  delay(75);
  BUZZER_ON;
  delay(75);
  BUZZER_OFF;
  if (!ALARM_CONDITION)
  {
    if (ideMode == FM_DIO || ideMode == FM_DOUT)
    {
      digitalWrite(LED1_GPIO, LOW);
    }
    taskManager.StopTask(&taskAlarmOn);
  }
}

void setup()
{
  Serial.begin(115200);
  Serial.println();

  Serial.printf("Flash ide mode:  %s\n", (ideMode == FM_QIO ? "QIO" : ideMode == FM_QOUT ? "QOUT" : ideMode == FM_DIO ? "DIO" : ideMode == FM_DOUT ? "DOUT" : "UNKNOWN"));
  
  Serial.print("Initializing GPIO... ");
  pinMode(BUZZER_GPIO, OUTPUT);
  analogWrite(BUZZER_GPIO, 0);
  if (ideMode == FM_DIO || ideMode == FM_DOUT)
  {
    pinMode(LED0_GPIO, OUTPUT);
    pinMode(LED1_GPIO, OUTPUT);
    digitalWrite(LED0_GPIO, HIGH);
    digitalWrite(LED1_GPIO, LOW);
  }
  pinMode(DUST_SNS_GPIO, OUTPUT);
  digitalWrite(DUST_SNS_GPIO, LOW);
  Serial.println("SUCESS");
  
  /* AD7792 reset, setup and internal calibration */
  Serial.print("Initializing AD7792... ");
  if (AD7792_Init() == 1)
  {
    Serial.println();
    Serial.print("Resetting AD7792... ");
    AD7792_Reset();
    Serial.println("SUCESS");

    AD7792_SetMode(AD7792_MODE_IDLE);
    
    uint16_t cfg_reg = AD7792_GetRegisterValue(AD7792_REG_CONF, 2, 0);
    Serial.print("CFG register contents after reset: ");
    Serial.println(cfg_reg);
    
    Serial.print("Disabling internal buffer and enabling unipolar mode... ");
    cfg_reg &= ~AD7792_CONF_BUF;     // Disable the internal buffer
    cfg_reg |= AD7792_CONF_UNIPOLAR; // Unipolar mode
    AD7792_SetRegisterValue(AD7792_REG_CONF, cfg_reg, 2, 0);
    Serial.println("SUCESS");
    
    Serial.print("Setting gain... ");
    AD7792_SetGain(AD7792_GAIN_1);
    Serial.println("SUCESS");

    Serial.print("Setting internal reference... ");
    AD7792_SetIntReference(AD7792_REFSEL_INT);
    Serial.println("SUCESS");
    
    Serial.print("Performing zero scale calibration... ");
    AD7792_Calibrate(AD7792_MODE_CAL_INT_ZERO, AD7792_CH_AIN1P_AIN1M);
    AD7792_Calibrate(AD7792_MODE_CAL_INT_ZERO, AD7792_CH_AIN2P_AIN2M);
    AD7792_Calibrate(AD7792_MODE_CAL_INT_ZERO, AD7792_CH_AIN3P_AIN3M);
    Serial.println("SUCESS");
    
    Serial.print("Performing full scale calibration... ");
    AD7792_Calibrate(AD7792_MODE_CAL_INT_FULL, AD7792_CH_AIN1P_AIN1M);
    AD7792_Calibrate(AD7792_MODE_CAL_INT_FULL, AD7792_CH_AIN2P_AIN2M);
    AD7792_Calibrate(AD7792_MODE_CAL_INT_FULL, AD7792_CH_AIN3P_AIN3M);
    Serial.println("SUCESS");

    Serial.print("Enabling gas sensor excitation current... ");
    AD7792_SetRegisterValue(AD7792_REG_IO, 
                            AD7792_IEXCEN(AD7792_EN_IXCEN_10uA) | AD7792_DIR_IEXC1_IOUT1_IEXC2_IOUT2,
                            1, 1);
    Serial.println("SUCESS");

    AD7792_SetMode(AD7792_MODE_CONT);
    
    _ad7792_present = true;
  }
  else
  {
    _ad7792_present = false;
    Serial.println("FAIL");
  }

  /* When SHT1x is created the driver only initializes GPIO                       */
  /* Read/write to the status register is performed to detect its actual presence */
  /* The 6th bit in the status register is read only and can have any value       */
  /* Hence, feedback can either be equal to 1 or to (1 | (1 << 6))                */
  Serial.print("Initializing SHT10... ");
  SHT1x.writeStatusReg(1);
  unsigned char feedback = SHT1x.readStatusReg();
  if ((feedback == 1) || (feedback == (1 | 1 << 6)))
  {
    _sht10_present = true;
    Serial.println("SUCESS");
  }
  else
  {
    _sht10_present = false;
    Serial.println("FAIL");
  }

  /* Creates the access point and assigns callbacks                                          */
  /* Sending a command to the server looks like 192.168.4.1/takeData                         */
  /* If there is no command, it is assumed to be empty (/)                                   */
  /* See handleRoot() and data() functions; data() is invoked everi second (see webPage.cpp) */
  boolean result = WiFi.softAP(_SSID, _PASS);
  IPAddress IP = WiFi.softAPIP();
  server.on("/", handleRoot);
  server.on("/takeData", data);
  server.begin();
  Serial.print("Setting soft-AP... ");
  if(result == true)
  {
    Serial.println("SUCESS");
  }
  else
  {
    Serial.println("FAIL");
  }
  Serial.print("Local IP: ");
  Serial.println(IP);

  taskManager.StartTask(&taskDataUpdater);
  taskManager.StartTask(&taskClientHandler);
}

/* Start the task scheduler kernel */
void loop()
{
  taskManager.Loop();
}

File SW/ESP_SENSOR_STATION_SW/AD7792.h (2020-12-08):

/***************************************************************************//**
 *   @file   AD7792.h
 *   @brief  Header file of AD7792 Driver.
 *   @author Bancisor Mihai
********************************************************************************
 * Copyright 2012(c) Analog Devices, Inc.
 *
 * All rights reserved.
 *
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
********************************************************************************
 *   SVN Revision: 501
*******************************************************************************/
#ifndef __AD7792_H__
#define __AD7792_H__

/******************************************************************************/
/* AD7792                                                                   */
/******************************************************************************/

/* AD7792 GPIO */
#define AD7792_RDY_STATE       GPIO1_STATE

/*AD7792 Registers*/
#define AD7792_REG_COMM		  0 /* Communications Register(WO, 8-bit) */
#define AD7792_REG_STAT	    0 /* Status Register	    (RO, 8-bit) */
#define AD7792_REG_MODE	    1 /* Mode Register	     	(RW, 16-bit */
#define AD7792_REG_CONF	    2 /* Configuration Register (RW, 16-bit)*/
#define AD7792_REG_DATA	    3 /* Data Register	     	(RO, 16-/24-bit) */
#define AD7792_REG_ID	      4 /* ID Register	     	(RO, 8-bit) */
#define AD7792_REG_IO	      5 /* IO Register	     	(RO, 8-bit) */
#define AD7792_REG_OFFSET   6 /* Offset Register	    (RW, 24-bit */
#define AD7792_REG_FULLSALE	7 /* Full-Scale Register	(RW, 24-bit */

/* Communications Register Bit Designations (AD7792_REG_COMM) */
#define AD7792_COMM_WEN		  (1 << 7) 			/* Write Enable */
#define AD7792_COMM_WRITE	  (0 << 6) 			/* Write Operation */
#define AD7792_COMM_READ    (1 << 6) 			/* Read Operation */
#define AD7792_COMM_ADDR(x)	(((x) & 0x7) << 3)	/* Register Address */
#define AD7792_COMM_CREAD	  (1 << 2) 			/* Continuous Read of Data Register */

/* Status Register Bit Designations (AD7792_REG_STAT) */
#define AD7792_STAT_RDY		(1 << 7) /* Ready */
#define AD7792_STAT_ERR		(1 << 6) /* Error (Overrange, Underrange) */
#define AD7792_STAT_CH3		(1 << 2) /* Channel 3 */
#define AD7792_STAT_CH2		(1 << 1) /* Channel 2 */
#define AD7792_STAT_CH1		(1 << 0) /* Channel 1 */

/* Mode Register Bit Designations (AD7792_REG_MODE) */
#define AD7792_MODE_SEL(x)		(((x) & 0x7) << 13)	/* Operation Mode Select */
#define AD7792_MODE_CLKSRC(x)	(((x) & 0x3) << 6) 	/* ADC Clock Source Select */
#define AD7792_MODE_RATE(x)		((x) & 0xF) 		/* Filter Update Rate Select */

/* AD7792_MODE_SEL(x) options */
#define AD7792_MODE_CONT		     0 /* Continuous Conversion Mode */
#define AD7792_MODE_SINGLE		   1 /* Single Conversion Mode */
#define AD7792_MODE_IDLE		     2 /* Idle Mode */
#define AD7792_MODE_PWRDN		     3 /* Power-Down Mode */
#define AD7792_MODE_CAL_INT_ZERO 4 /* Internal Zero-Scale Calibration */
#define AD7792_MODE_CAL_INT_FULL 5 /* Internal Full-Scale Calibration */
#define AD7792_MODE_CAL_SYS_ZERO 6 /* System Zero-Scale Calibration */
#define AD7792_MODE_CAL_SYS_FULL 7 /* System Full-Scale Calibration */

/* AD7792_MODE_CLKSRC(x) options */
#define AD7792_CLK_INT		  0 /* Internal 64 kHz Clk not available at the CLK pin */
#define AD7792_CLK_INT_CO	  1 /* Internal 64 kHz Clk available at the CLK pin */
#define AD7792_CLK_EXT		  2 /* External 64 kHz Clock */
#define AD7792_CLK_EXT_DIV2	3 /* External Clock divided by 2 */

/* Configuration Register Bit Designations (AD7792_REG_CONF) */
#define AD7792_CONF_VBIAS(x)  (((x) & 0x3) << 14) 	/* Bias Voltage Generator Enable */
#define AD7792_CONF_BO_EN	    (1 << 13) 			      /* Burnout Current Enable */
#define AD7792_CONF_UNIPOLAR  (1 << 12) 			      /* Unipolar/Bipolar Enable */
#define AD7792_CONF_BOOST	    (1 << 11) 			      /* Boost Enable */
#define AD7792_CONF_GAIN(x)	  (((x) & 0x7) << 8) 	  /* Gain Select */
#define AD7792_CONF_REFSEL(x) (((x) & 0x1) << 7) 	  /* INT/EXT Reference Select */
#define AD7792_CONF_BUF		    (1 << 4) 				      /* Buffered Mode Enable */
#define AD7792_CONF_CHAN(x)	  ((x) & 0x7) 			    /* Channel select */

/* AD7792_CONF_GAIN(x) options */
#define AD7792_GAIN_1       0
#define AD7792_GAIN_2       1
#define AD7792_GAIN_4       2
#define AD7792_GAIN_8       3
#define AD7792_GAIN_16      4
#define AD7792_GAIN_32      5
#define AD7792_GAIN_64      6
#define AD7792_GAIN_128     7

/* AD7792_CONF_REFSEL(x) options */
#define AD7792_REFSEL_INT   1	/* Internal Reference Selected. */
#define AD7792_REFSEL_EXT   0	/* External Reference Applied between REFIN(+) and REFIN(�). */

/* AD7792_CONF_CHAN(x) options */
#define AD7792_CH_AIN1P_AIN1M	  0 /* AIN1(+) - AIN1(-) */
#define AD7792_CH_AIN2P_AIN2M	  1 /* AIN2(+) - AIN2(-) */
#define AD7792_CH_AIN3P_AIN3M	  2 /* AIN3(+) - AIN3(-) */
#define AD7792_CH_AIN1M_AIN1M	  3 /* AIN1(-) - AIN1(-) */
#define AD7792_CH_TEMP			    6 /* Temp Sensor */
#define AD7792_CH_AVDD_MONITOR	7 /* AVDD Monitor */

/* ID Register Bit Designations (AD7792_REG_ID) */
#define AD7792_ID			    0xA
#define AD7792_ID_MASK		0xF

/* IO (Excitation Current Sources) Register Bit Designations (AD7792_REG_IO) */
#define AD7792_IEXCDIR(x)	(((x) & 0x3) << 2)
#define AD7792_IEXCEN(x)	(((x) & 0x3) << 0)

/* AD7792_IEXCDIR(x) options*/
#define AD7792_DIR_IEXC1_IOUT1_IEXC2_IOUT2	0  /* IEXC1 connect to IOUT1, IEXC2 connect to IOUT2 */
#define AD7792_DIR_IEXC1_IOUT2_IEXC2_IOUT1	1  /* IEXC1 connect to IOUT2, IEXC2 connect to IOUT1 */
#define AD7792_DIR_IEXC1_IEXC2_IOUT1		    2  /* Both current sources IEXC1,2 connect to IOUT1  */
#define AD7792_DIR_IEXC1_IEXC2_IOUT2		    3  /* Both current sources IEXC1,2 connect to IOUT2 */

/* AD7792_IEXCEN(x) options*/
#define AD7792_EN_IXCEN_10uA				1  /* Excitation Current 10uA */
#define AD7792_EN_IXCEN_210uA				2  /* Excitation Current 210uA */
#define AD7792_EN_IXCEN_1mA					3  /* Excitation Current 1mA */

/******************************************************************************/
/* Functions Prototypes                                                       */
/******************************************************************************/

/* Initialize AD7792 and check if the device is present*/
unsigned char AD7792_Init(void);

/* Sends 32 consecutive 1's on SPI in order to reset the part. */
void AD7792_Reset(void);

/* Reads the value of the selected register. */
unsigned long AD7792_GetRegisterValue(unsigned char regAddress, 
									  unsigned char size,
                                      unsigned char modifyCS);

/* Writes a value to the register. */
void AD7792_SetRegisterValue(unsigned char regAddress,
							 unsigned long regValue, 
							 unsigned char size,
                             unsigned char modifyCS);

/* Waits for RDY pin to go low. */
void AD7792_WaitRdyGoLow(void);

/* Sets the operating mode of AD7792. */
void AD7792_SetMode(unsigned long mode);     

/* Selects the channel of AD7792. */
void AD7792_SetChannel(unsigned long channel);

/* Sets the gain of the In-Amp. */
void AD7792_SetGain(unsigned long gain);
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

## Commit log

2020-12-08 Реорганизация репозитория
    [Bill of Materials-ESP_SENSOR_STATION_REV1.xlsx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]
2020-12-08 Добавление базовой информации по корпусу и dummy папки DOCS
    [User Library-SS-7B plug.STEP]
2020-12-08 Пре-релиз корпуса
    [Крышка.stl, Основание.stl]
2020-12-09 Правки в корпус
    [Крышка.stl]
2020-12-12 Отлажена большая часть функционала устройства
    [Крышка.stl, Основание.stl]
2021-05-25 Pre-publishing cleanup
    [ESP_SENSOR_STATION_REV1.SchDoc]
2021-05-25 Added renarks about the SW part
    [UMS5_Корпус.3mf, User Library-SS-7B plug.STEP]
